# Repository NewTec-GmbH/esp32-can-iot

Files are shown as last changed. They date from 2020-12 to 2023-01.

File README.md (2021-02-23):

# ESP CAN-Analyzer
An ESP32 based interface between CAN-Bus and IoT environments.

This project has the main objective of interfacing a CAN Bus with the user through the use of the Lawicel Protocol (also known as SLCAN). Lawicel represents CAN Frames as strings of ASCII Symbols which can be easily interpreted by the user of by the numerous applications available online. 

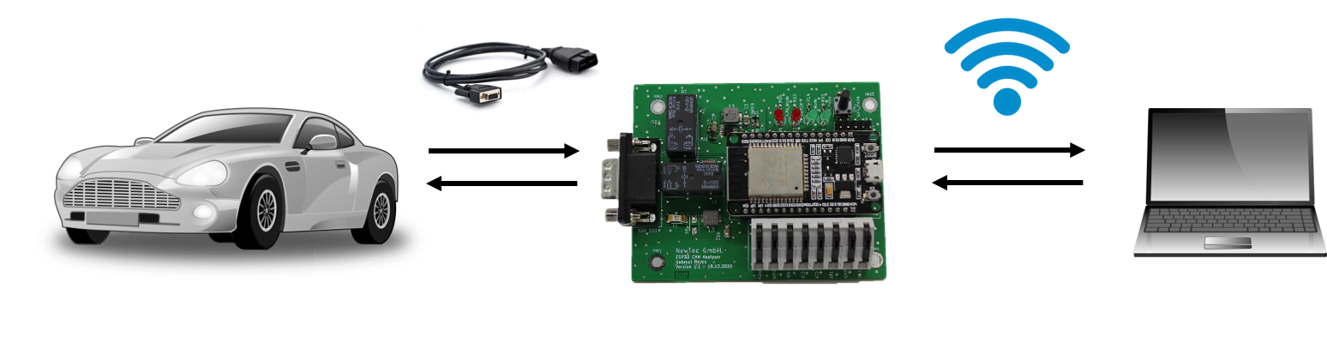
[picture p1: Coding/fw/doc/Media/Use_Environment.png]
Use_Environment


- [Technical Specifications](#Technical-Specifications)
	- [Software Requirements](#Software-Requirements)
	- [Hardware Requirements](#Hardware-Requirements)
	- [Extra/Optional Requirements](#Extra/Optional-Requirements)
- [Context](#Context)
- [Use Case](#Use-Case)
- [Potential Optimization](#Potential-Optimization)
- [Specialized Pages](#Specialized-Pages)

# Technical Specifications 
## Software Requirements
* Support Standard and Extended frame formats
* WiFi Mode Selection (AP or STA)
* Support *Lawicel* Protocol
* HTTP Server over WiFi
* Server shall support authentication
* AP credentials changed through Server
* STA credentials changed through Server
* Bit Timing and Filters changed through Server
* CAN monitoring page (depending on available memory)
* Send CAN frame on demand
* Send CAN frame periodically
* CAN BUS Termination on Demand

## Hardware Requirements
* ESP32-based
* ISO 11898 Compliant (CAN up to 1 Mbps)
* CAN Bus Termination on Demand
* Support CAN through DSUB-9
* Support OBD through DSUB-9
* Bus-off State
* ISO 7637 compliant (Road vehicles -- Electrical disturbances from conduction and coupling)
* Control Button
* Red Error LED
* 4 GPIOs via Clamps

## Extra/Optional Requirements
* Identification of Error Message
* Reset through Webserver (Save and Restart)
* View OBD Messages (.dbc file?)
* LAWICEL over websocket/mqtt (to nodejs/node-red)

# Context
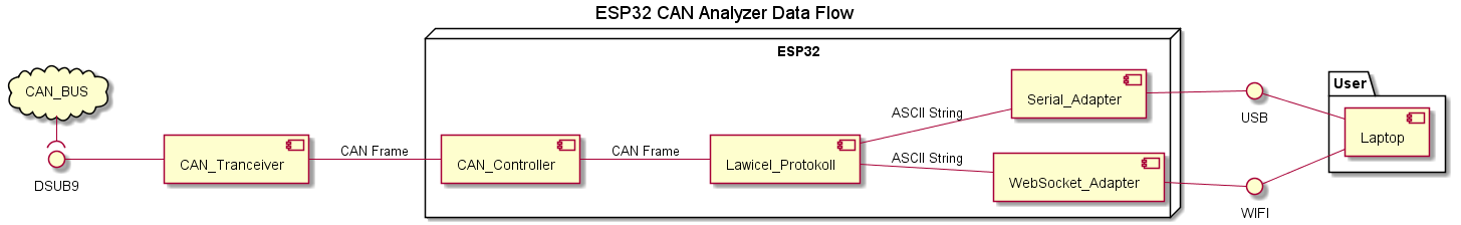
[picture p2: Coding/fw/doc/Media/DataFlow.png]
DataFlow


Based on the Lawicel Protocol, this project connects any standard CAN Bus to the user-end system. One example is its use on the Automotive Environment, where the CAN Bus is acquired through the DSUB-9 connector. The Frames are parsed through Lawicel into an ASCII String and sent through Serial to the Users Laptop. There is a second option, which is sending this String through a Websocket to the user. This enables the use of other IoT tools on the user's side, for example, Node-Red.

# Use Case
UseCaseAnalyzer

The use case for this project is based on the direct connection to a CAN Bus, in order to obtain the information being sent between the members of this bus. On the other side of this communication we find a Serial Interface or a Websocket Interface which presents the information to the user. The user has to provide the device with the characteristics of the Bus it is connected to, in order to correctly acquire the data.

# Potential Optimization

Thisproject has the potential to be improved in many of its aspects, specially its Firmware. These are some of the points that have been noted during the development, which can be improved in order to increase the performance:

* Lawicel commands active during AP Mode
* Use of Binary Lawicel Commands instead of Strings
* Optimize the Websocket Buffering of Messages (in both directions)
* Use of both Cores for Tasking
* Send Cyclic Frames using a Lawicel Command
* Prevent reset after car's start/stop

# Specialized Pages

* [Hardware](./Hardware/README.md)
* [Firmware](./Coding/fw/README.md)
	* [Documentation](./Coding/fw/doc/README.md)
	* [Libraries](./Coding/fw/lib/README.md)
		* [Lawicel Protocol](./Coding/fw/lib/Lawicel/README.md)
		* [CAN](./Coding/fw/lib/CAN/README.md)
	* [Application](./Coding/fw/src/README.md)
	* [Unit Test](./Coding/fw/test/README.md)
* [Glosary](./Coding/fw/doc/Glosary.md)

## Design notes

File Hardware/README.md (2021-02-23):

# Hardware Description

- [Architecture](#Architecture)
- [Implementation](#Implementation)
    - [CAN/OBD-II Switching](#CAN/OBD-II-Switching)
    - [Components](#Components)
    - [Version 1.0](#Version-1.0)
    - [Version 1.1](#Version-1.1)

# Architecture
Hardware_Overview

This deviced is based on the ESP32­-WROOM-­32E processor, which has a diverse number of interfaces such as digital and analog inputs and output, as well as an integrated CAN bus controller and WiFi capabilities, between many other characteristics. The ESP32 additionally needs a CAN Transceiver to receive the data from the CAN-H and CAN-L lines. 

The connection to the CAN Bus is done through a DSUB-9 connector, which is the standard for CAN busses. This connector can also provide a the device with power, but with a 12V voltage which has to be reduced to 5V before going into the ESP32 DevKit, where it will be transformed again into 3.3V.

# Implementation
The Project was developed using KiCad and all its Toolchain. This includes Eeschema, Pcbnew and GerbView.

## CAN/OBD-II Switching
In order to implement this device in the automotive environment it is necessary to adapt the standard connector found in cars (OBD-II) to the standard CAN connector (D-SUB9).
This is achieved by using an OBD-II to DB9 Cable, from Sparkfun for example. The problem with this solution is that the cable does not use the same pins for the High and Low signals of the CAN-Bus:

| Pin | OBD-II | DSUB-9 |
| :---: | :---: | :---: |
| 2 | GND | CAN-LOW |
| 3 | CAN-HIGH | GND |
| 5 | CAN-LOW | --- |
| 7 | --- | CAN-HIGH |
| 9 | 12V | --- |

The main issue is the connection of the CAN signals to Ground, as this would turn off the Bus in all of its nodes and this should be prevented at all costs. 

Our solution is the use of one analog pin on the microcontroller, which detects the incoming 12V at Pin 9 when using the OBD-II option (through a 10:1 voltage divider). If the analog signal is present, two relays are closed to change the connections of the D-SUB9 connector to the rest of the board.

This solution has been proved effective and quick enough so no the bus is not distrubed in any way.

## Components

The following components were selected for this project's PCB. Smaller components such as resistors and capacitors are not included in this list, but can be found on the [BOM](./010_Implementation/BOM.xlsx).

| Component | Description |
| :---: | :---: |
| ESP32-DEVKITC-32D | Microprocessor used. Connected using socket strips |
| SS24 | Safety diode for Microprocessor in case more than one power supply is being used |
| TPS62160DGK | 12V 1A Step-down Converter |
| R452002 | 12V Fuse |
| SMAJ16A | Protective Diode at 12V input |
| G5V-2-DC5 | Relay for "smart" switching between CAN and OBD Pinout |
| BC817 | Transistor for Relay control |
| 1N4148 | Diodes for Relay protection |
| DSUB9 | Standard connector for CAN-Bus |
| SN65HVD233-HT | CAN Transceiver |
| 744242220 | Toroid for CAN-Bus Filtering |
| PESD1CAN | Diode for CAN-Bus Filtering |
| AST 045-08 | 8-position connector with latches for GPIO |
| CAB-10087 | OBD-II to DB9 Cable |

## Version 1.0
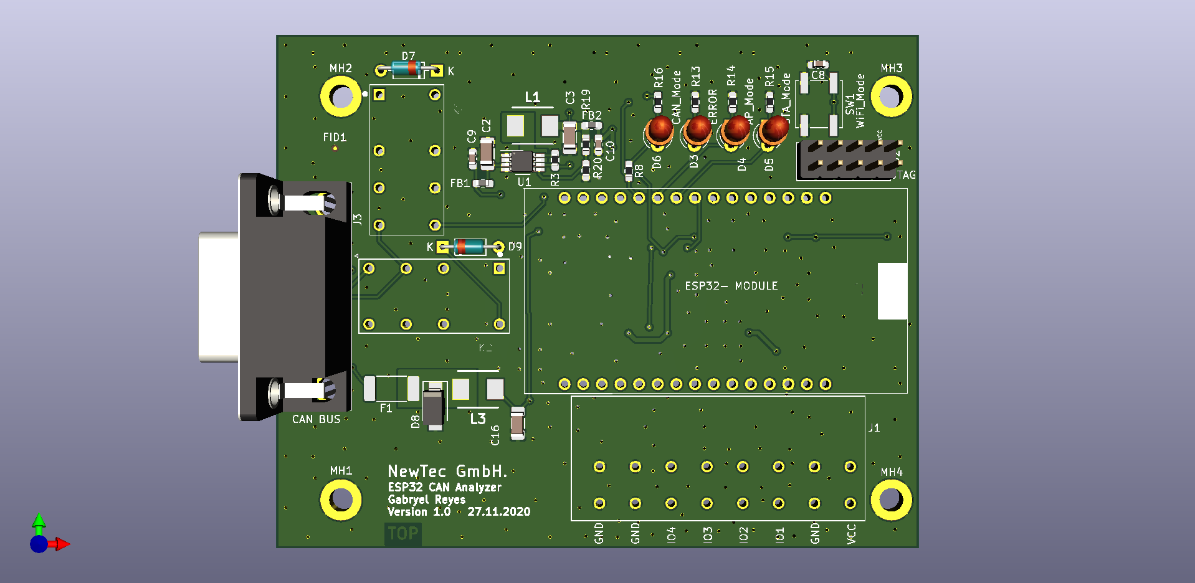
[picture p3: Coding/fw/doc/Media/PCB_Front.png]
Version 1.0_Front
 
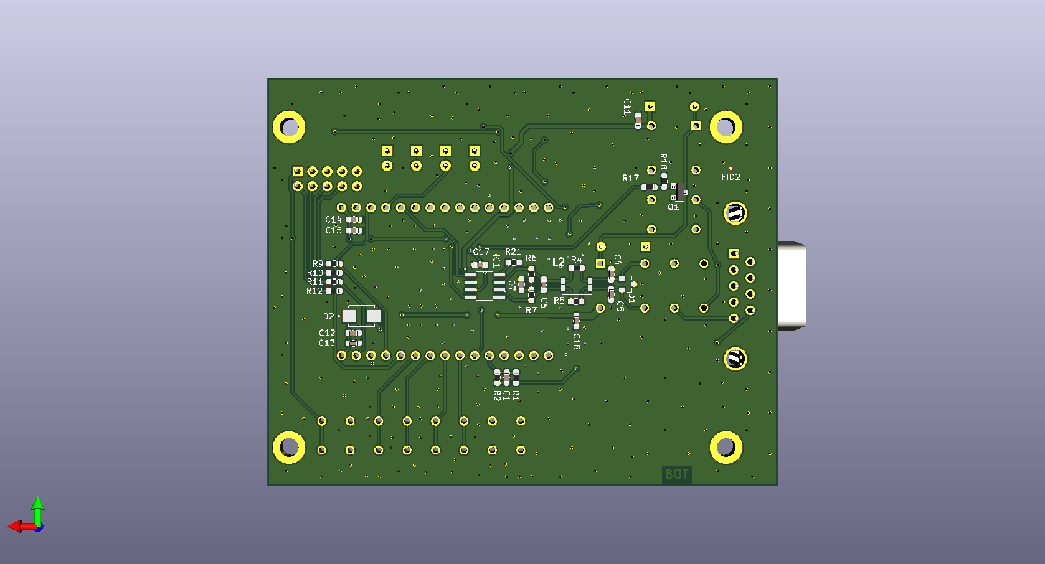
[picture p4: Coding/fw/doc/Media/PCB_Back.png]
Version 1.0_Back


## Version 1.1
2 Main Errors were found on Version 1.0:
* Tx and Rx Signals from the CAN Transceiver were inverted
* The 5V Supply for the Relays was located after a diode, which prevented the use of the relays when connected only through USB Supply. 

In the new version were these two changes made and after testing it resolved in success.

Other minor errors were also repaired, such as the size of the holes for AST 045-08 Connector which were too small.

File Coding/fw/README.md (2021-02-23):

# Firmware Description

- [Software Architecture](#Software-Architecture)
	- [Software Overview](#Software-Overview)
	- [Applicaton Entry Points Processing](#Applicaton-Entry-Points-Processing)
- [Detailed Design](#Detailed-Design)
	- [Main Application](#Main-Application)
	- [Lawicel](#Lawicel)
	- [Web Server](#Web-Server)
	- [Web Socket](#Web-Socket)
- [Software-Hardware Integration](#Software-Hardware-Integration)

# Software Architecture
## Software Overview
Hierarchy

The Firmware is composed by 4 main layers: Application, Modules, Service and HAL. As the software is built on the Arduino Framework, the Arduino.h Library is found on the HAL as the interfacing class between hardware and software. This library contains a great number of sub-libraries which independently control each piece of hardware.

On the Service Layer we can find the Board Class, as an abstraction from the Arduino library to be able to use only the needed GPIO adn their respective methods. Here we can also find the library for the CAN Controller and the IP Stack used by the Webserver.

On the Modules Layer we find the implemented classes: Lawicel and ESPAsyncWebServer, which use the Service Layer to effectively transmit information. Both these Classes are controlled by the Application Layer, which ultimately defines the behavior of the system.

Detailed information on the implemented libraries can be found in the [Library](./lib/README.md) Documentation, as well as online in the case of the Arduino Library.

## Applicaton Entry Points Processing
The following diagram pictures the Entry Points called by the Application while the programm is running. The code where this sequence can be found is contained in the [main.cpp](./src/main.cpp) file. 

MainLoop

The process is divided in two main sections, as per Arduino Framework standard:

### Setup
This section is only called once everytime the system reboots. It initializes the different Modules that compose the system, and expects a Boolean **True** return from each Module in order to continue with the normal routine. If any of the Modules returns a **False** value instead, a System Halt is called from the Board Class.

The Board initialization sets up the HAL by defining which pins are going to be use and their respective modes, for example, Pin 2 is configured as an output in order to be used as the Error LED.

The Lawicel Protocol in its initialization routine also configures each of the Adapters passed as arguments on its constructor. This means that here is the CAN Controller started, as well as the Web Server and Socket when the respective adapter is passed. In the case of having Auto-start configured in Lawicel, the saved parameters are retrieved from the NVM and set up accordingly. Each of these processes is expected to return a **True** value. 

### Loop
As its name describes, the loop is called in a cyclic manner every time it finished its routine. 
Here is the Lawicel Cycle called, where the communication from/to the user occurs. In this case a **False** response does *NOT* call a System Halt, but only a blink on the Error LED as this means the user entered an invalid command. 

The Loop is also constantly checking on the Wireless connection to the configure network to ensure no data-loss. 

Finally, it checks if a system restart is called from the Captive Portal. If this is the case, all modules are halted and the OS is restarted.  

# Detailed Design
## Main Application
The system follows the following procedure during the Setup:

Setup

As mentioned on the Software Architecture, during the Setup Process, any error or **False** return value will call a System Halt, as the configuration of each module is critical for the correct operation of the whole system. 

## State Machine
The ESP CAN-Analyzer has two main modes, AP-Mode and STA-Mode. AP refers to Access Point, where the ESP creates its own Wireless Network and serves only a Captive Portal to work as a Configuration Portal for the STA Credentials. On the other side, STA is the abbreviation for Station, which is the normal mode for the system. The Station Mode uses the user's WiFi credentials to connect to the wireless local network. This mode works as a server through which the Lawicel Protocol can communicate using a websocket.

StateMachine

## Lawicel

The Lawicel Module implements one of the most important components of this project. The Lawicel Protocol is used to communicate witha CAN Bus using ASCII symbols, as each command that is sent has a specific format, as described in the Library's Documentation. 

The module is composed by 4 main components: the implementation of the protocol, an interface for serial communication, an interface for CAN communication and an interface for Non-Volatile Memory. These Interfaces define the functions that the adapters must perform and are directly used by the protocol. Through the use of these, it is possible to handle the Lawicel Module as a completely independent component to which different adapters can be connected depending on the case and hardware used.

Arch_Lawicel

In this case, the adapters are implemented for the ESP32 and the libraries used by it. In the case of the Serial Adapter, it employs directly the Serial hardware from the Arduino Library; however a Web Socket Adapter is also implemented in order to communicate with other IoT systems. For the NVM Adapter, the ESP32 offers a library for managing flash memory using keys, which is called "Preferences". Finally the CAN Adapter is an abstraction from sandeepmistry's [arduino-CAN](https://github.com/sandeepmistry/arduino-CAN), which manages the memory-mapped SJA1000 CAN Controller.

## Web Server
The second most important module is the Webserver. The ESP32 offers the capability of hosting a server that manages the requests asynchron, meaning that it does not block the other tasks that the processor has to complete. This server is an implementation of me-no-dev's [ESPAsyncWebServer](https://github.com/me-no-dev/ESPAsyncWebServer).

Arch_Webserver

The server uses 3 service classes: 
* **WebConfig** contains the constants and important configurations required by the server, such as the possible HTTP Responses. 
* **WebSocket** handles the communication between the client and the WebSocket Adapter for Lawicel.
* **Pages** configures the handling of the Webpages for STA Mode. 
* **Captive Portal** is initiated when AP Mode is active instead, in order to provide the users with an interface to change the credentials for the Station Mode. 
	* Both of these classes, Pages and Captive Portal, use the Serial Peripheral Interface Flash File System (SPIFFS) which stores the Webpages as HTML files and serves them to the web clients when requested.

Arch_Webpages

## Web Socket
As a substitution of the SerialAdapter, a WebSocketAdapter has been implemented. The goal of this is to communicate through the WebServer into a Webpage or an external IoT application (such as Node-Red). The Library for this implementation is included on the AsyncWebServer Library.

Arch_Websocket

# Software-Hardware Integration
Regarding the software, the device sets different LEDs as to show the state of the system, for example to show when a system critical error has occurred or when the Access Point Mode is enabled. The system also has communication with a CAN Transceiver which performs the connection to the bus. The user plays an important role as the they must configure the bus characteristics as well as the needed credentials for the Station Mode. 

UseCaseSoftware

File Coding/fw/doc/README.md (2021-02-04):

# Documentation
This folder contains the Documentation for the ESP32 CAN-Analyzer Project. 

## Design
The Project is described using numerous UML Diagrams in order to give a better image and perspective of how Software and Hardware are composed. These are written using PlantUML and are included in several of the ReadMe files on this project. 

## Software Environment
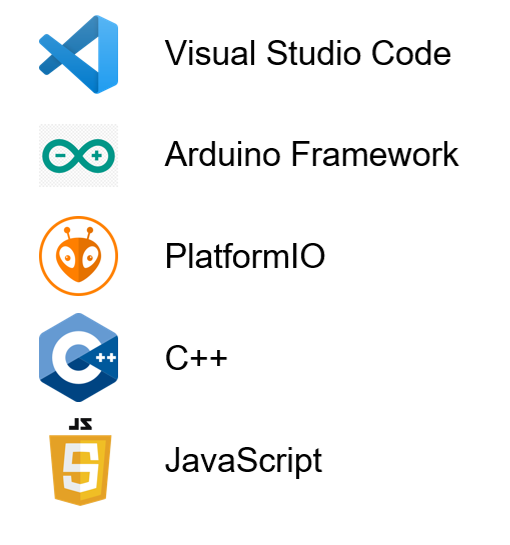
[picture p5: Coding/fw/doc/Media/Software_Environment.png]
Software Environment


This project has been developed using PlatformIO IDE as a plugin of Visual Studio Code. This platform provides the libraries and drivers needed to work with the chosen microcontroller. 

The Firmware has been written using C++, while the Web-application has been developed using JavaScript.

## Doxygen
The software for this project has been documented using Doxygen, using a [Doxyfile](./doxyfile) to store the configuration. 
It is possible to parse the Documentation using the [Doxywizard](https://www.doxygen.nl/download.html) Programm and this configuration file.

## Media
This folder contains images of the project

## Node-Red
Here are the referencial images and Flows for the complementary Node-Red Flows

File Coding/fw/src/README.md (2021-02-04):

# Main Application
The ESP32 CAN-Analyzer main application is composed of the Main Loop, and the Adapters corresponding to the Lawicel Interfaces for Serial, NVM and CAN Modules. These Adapters are specific to the platform, hardware and libraries being used.

- [Main Loop](#Main-Loop)
- [Adapters](#Adapters)
    - [CAN Adapter](#CAN-Adapter)
    - [NVM Adapter](#NVM-Adapter)
    - [Serial Adapter](#Serial-Adapter)

# Main Loop
This contains the standard Arduino "Setup" and "Loop" functions, which control the whole program. The instances of the Adapters and the Lawicel Protocol are also defined in this file. It is important to note that the application stops running if a catastrophioc error is encountered, for example, being unable to connect to the user-given Wireless Network

# Adapters
These are the implementations of the Lawicel Interfaces. The Protocol required one adapter of each kind to work properly:

## CAN Adapter
This file contains the methods used by the CAN Controller. 

Its objetive is to receive the Frames from the Bus and write them in the format of the Frame Struct, which gets passed onto the Lawicel Protocol for its processing. 

On the other side, it also receives the Frames from the Lawicel Protocol which get sent onto the connected Bus.

This section is also responsible for setting the user-selected configuration of the CAN Device, such as Baudrate, Filters, and current Status.

For this project, the Adapter wraps around the [Arduino-CAN](https://github.com/sandeepmistry/arduino-CAN) Library, but it has been copied onto the libs folder to be able to fully implement the Lawicel Commands for the integrated SJA1000 Controller.

## NVM Adapter
This file contains the methods for saving and retrieving data from the non-volatile memory of the ESP32, using the Preferences Library as base.

As there are some parameters that need to be saved between power cycles, such as the wireless credentials, this adapter simplifies and centralizes the access to the saved data. This is achieved using keys and directories to order and store the data, as well as the easy retrieval when requested.

## Serial Adapter
Here is the interface between the Device and Humans found. The Serial Adapter trasmits the output of the Lawicel Protocol, as well as the user input into Lawicel. For the project, two versions of the Serial Adapter have been developed: serialAdapter and WebSocketAdapter. 

SerialAdapter interfaces with the Arduino Serial (UART) interface, while the WebSocketAdapter connects to the WebSocket, so the system can be used through a Wireless network. By default, the WebSocketAdapter is configured.

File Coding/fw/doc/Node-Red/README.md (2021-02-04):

# Node-Red Integration

Node-RED is a programming tool for wiring together hardware devices, APIs and online services in new and interesting ways.

It provides a browser-based editor that makes it easy to wire together flows using the wide range of nodes in the palette that can be deployed to its runtime in a single-click.

For this project, a Node-Red Flow has been developed to monitor the state of a car through its CAN Bus. It is based on using PID Requests to the Car's ECU using the [SAE Standard](https://en.wikipedia.org/wiki/OBD-II_PIDs).

# Data Collection
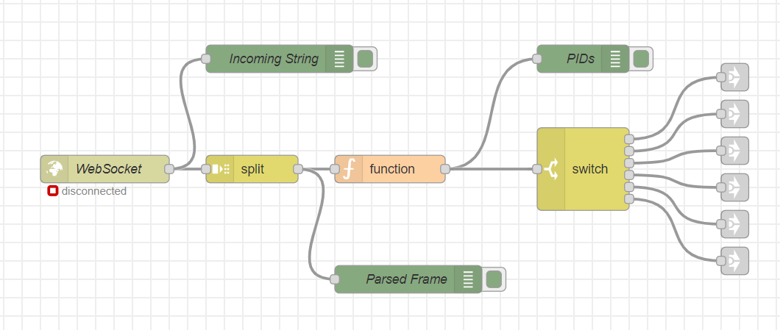
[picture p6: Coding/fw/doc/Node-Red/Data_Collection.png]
Data Collection


This Flow receives the information from the WebSocket and parses the CAN Frame using the Lawicel Protocol. Then only the Frames which comply with the SAE Standard are allowed through to be analyzed/displayed.

# Vehicle Data
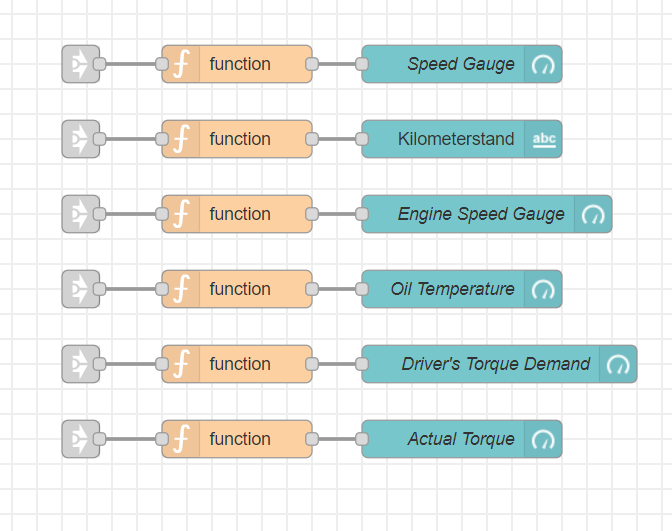
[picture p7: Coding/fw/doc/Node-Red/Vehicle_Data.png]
Vehicle Data


Here are the PIDs received and the Vehicle Data extracted from the Frame's data bytes. Then the information is sent to the Dashboard

# Dashboard
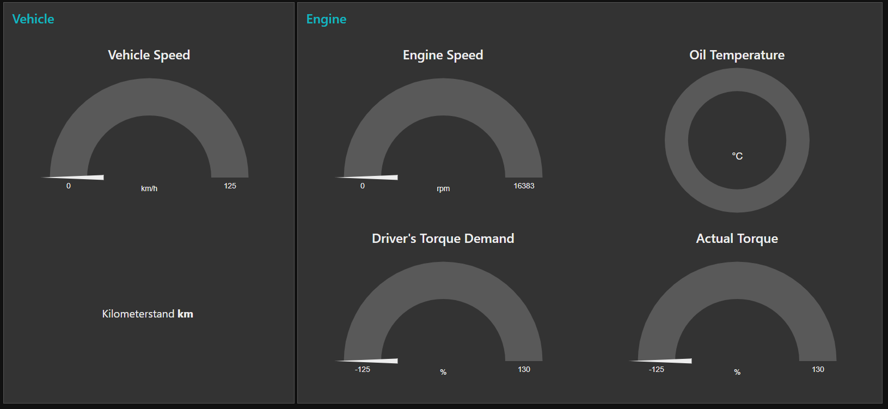
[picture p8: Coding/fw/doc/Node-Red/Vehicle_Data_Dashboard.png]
Dash


The Node-Red Dashboard includes several types of gauges and displays to show the information in the best way possible. Here we have 4 Gauges, one Donut and one text block.

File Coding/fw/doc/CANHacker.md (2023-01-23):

# Connection to CANHacker Software

CANHacker is a Graphical Interface for CAN Adapters that communicate using the Lawicel Protocol, such as this project.

In order to connect to this application, the Serial Adapter must be used instead of the WebSocket.

## Main.cpp
The correct "main.cpp" would look like this:

```cpp

// Includes
#include <Arduino.h>
#include "Lawicel.h"
#include "Board.h"
#include "SerialAdapter.h"
#include "CANAdapter.h"
#include "NVMAdapter.h"

static SerialAdapter gSerialAdapter; /**< Serial Adapter Instance */
static CANAdapter gSja1000Adapter;   /**< CAN Adapter Instance */
static NVMAdapter gFlashAdapter;     /**< NVM Adapter Instance */

/** Lawicel Protocol Instance */
static Lawicel gProtocolLawicel(gSerialAdapter, gSja1000Adapter, gFlashAdapter);

/**
 *  Initialization of Application
 */
void setup()
{
    Board::init();
    if (!gProtocolLawicel.begin())
    {
        Board::haltSystem();
    }
}

/**
 *  Application Loop
 */
void loop()
{   
    gProtocolLawicel.executeCycle();
}
```

## CANHAcker

Using the latest CANHacker Version (V.2.00.02), the connection is performed in two steps:

- Settings Windows: Set the `COM Port`, `Serial Baudrate` (default. 115200 bit/s), and `CAN Baudrate`. Other options such as "Listen Only" and "Timestamp" can be selected here too.

- Connect Button: Performs the connection to the device itself.

To check if your device is succesfully connected, the bottom bar should display the current state as "Connected to <<`CAN Baudrate`>> kbit/s" and the current Firmware Version (current: V1.01)

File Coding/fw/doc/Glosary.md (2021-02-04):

# Glosary

## AP
Abbreviation of Access Point. 
Device that creates a Wireless Area Network (WLAN).

## NVM
Abbreviation of Non-Volatile Memory.
Memory that does not need energy to contain data. The information is still saved even after a power cycle

## STA
Abbreviation of Station.
Device connects itself to a Wireless Area Network.

## SSID
Abbreviation of Service Set Identifier.
Name of the Wireless Area Network to be connected to in Station Mode, or to create as Access Point Mode

## WS
Abbreviation of Web Socket.
Full-Duplex and bidirectional communication protocol for communication through an unique Socket between Client and Server.

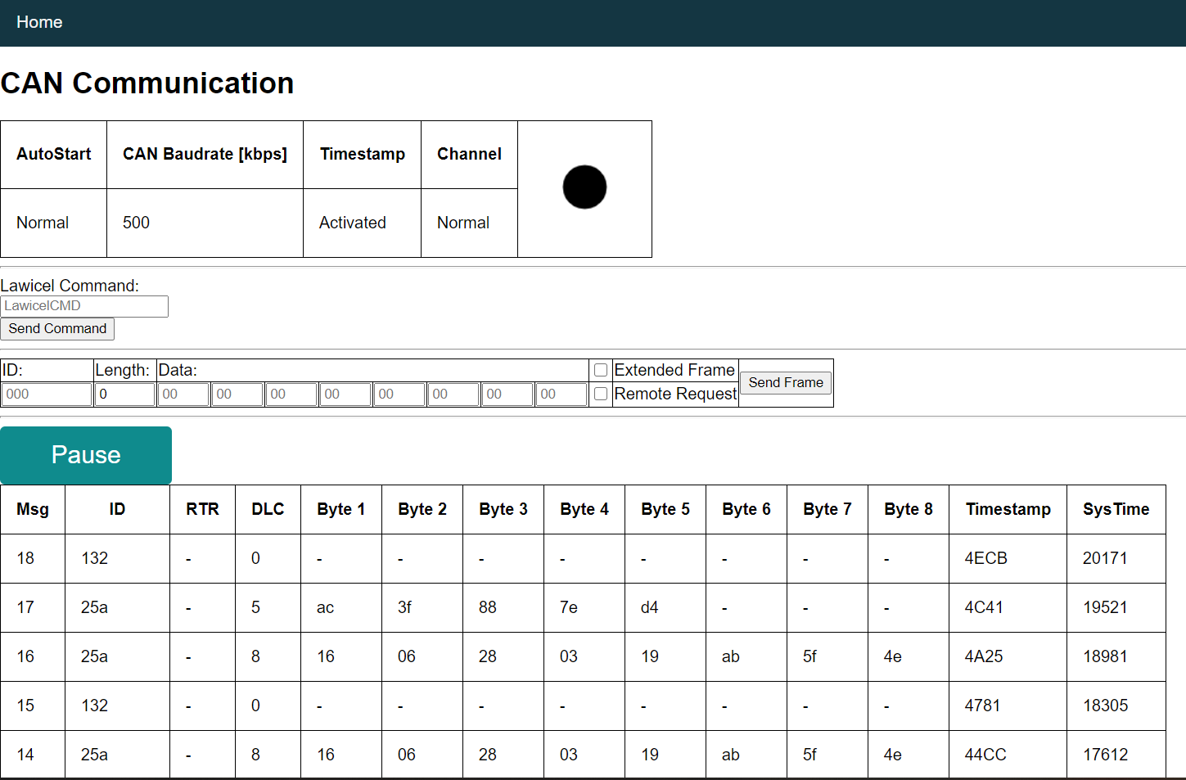
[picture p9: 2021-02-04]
Coding/fw/doc/Media/WebPage Design.png

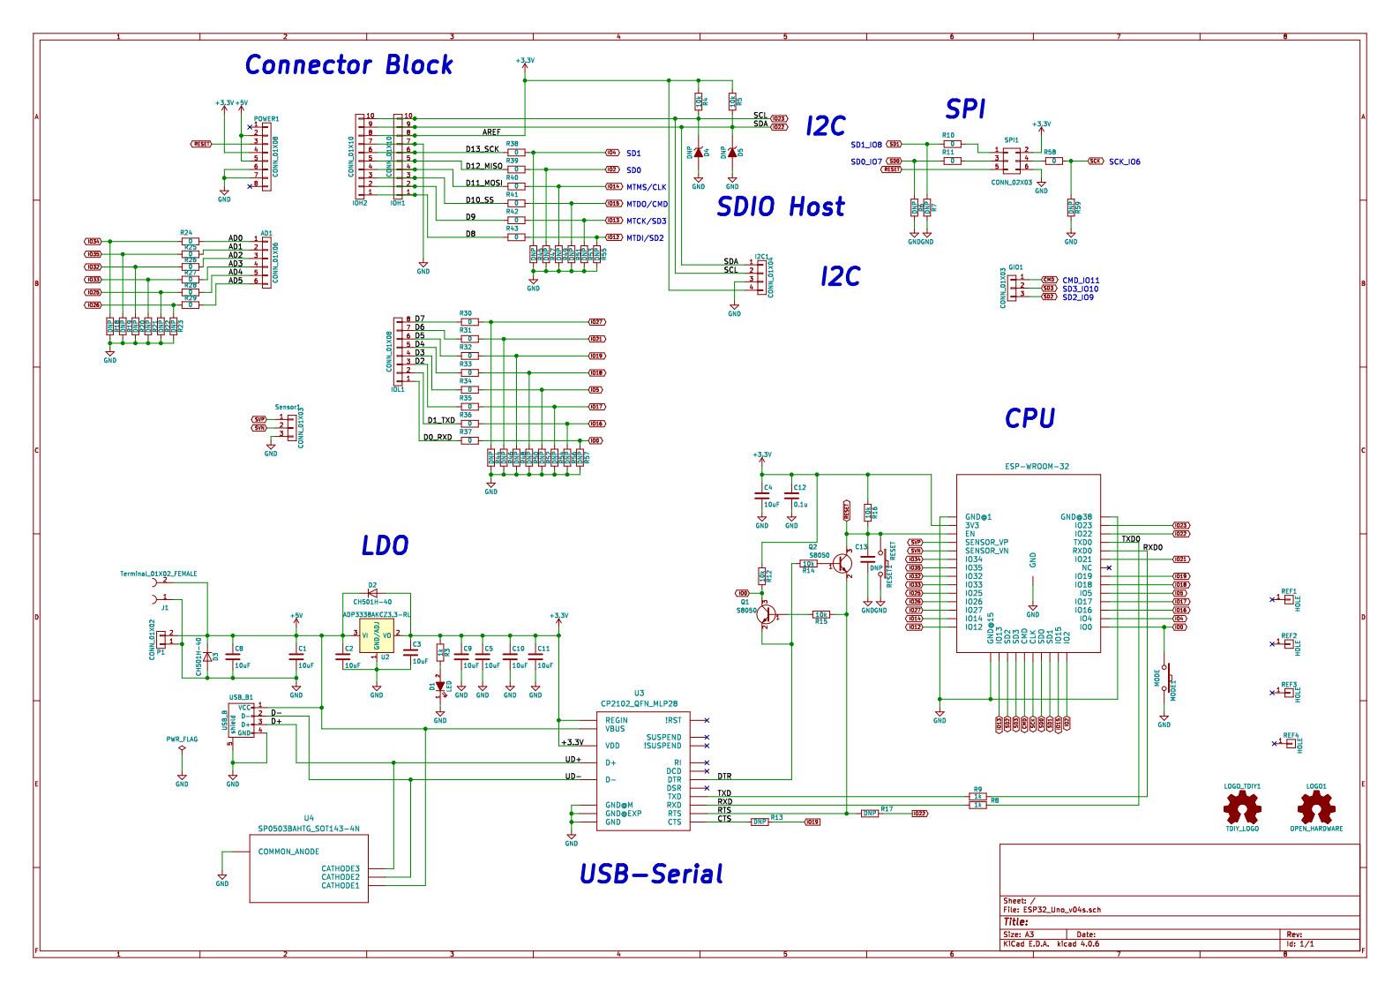
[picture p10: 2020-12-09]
Hardware/040_Data_Sheets/esp32-devkit Schematic.jpg

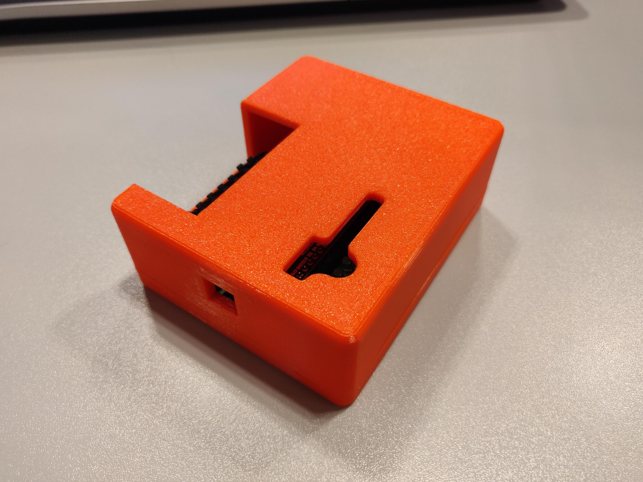
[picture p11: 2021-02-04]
Coding/fw/doc/Media/HW_Case4.png

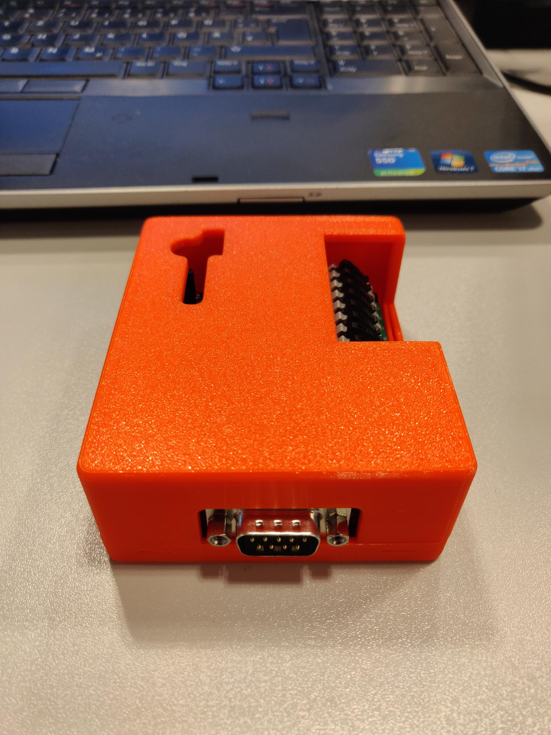
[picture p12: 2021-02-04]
Coding/fw/doc/Media/HW_Case1.png

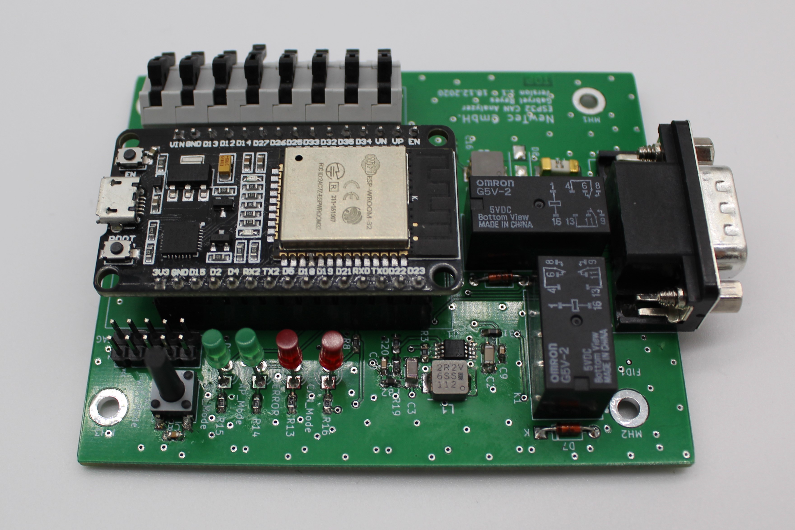
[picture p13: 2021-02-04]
Coding/fw/doc/Media/HW_Final3.jpg

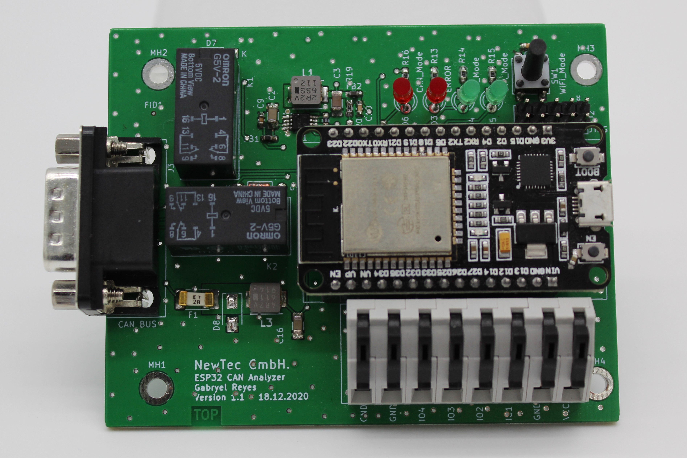
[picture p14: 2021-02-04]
Coding/fw/doc/Media/HW_Final2.jpg

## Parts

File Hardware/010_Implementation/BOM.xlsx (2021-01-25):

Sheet: Board
Id | Designator | Package | Quantity | Designation | NewTec | Digikey
1 | REF**,REF**,REF** | MountingHole_3.2mm_M3_DIN965_Pad | 3 | MountingHole_3.2mm_M3_DIN965_Pad | X
2 | J1 | AST 045-08 | 1 | Conn_01x08_Female | X
3 | K2,K1 | RELAY_G5V-2-DC5 | 2 | G5V-2-DC5 |  | X
5 | L1 | INDPM5550X300N | 1 | 2.2u | X |  | https://www.digikey.de/short/zv370m
6 | L3 | INDPM5550X300N | 1 | 5u | X
7 | U1 | VSSOP-8_3.0x3.0mm_P0.65mm | 1 | TPS62160DGK |  | X
8 | R21,R5,R4 | R_0603_1608Metric_Pad0.98x0.95mm_HandSolder | 3 | 0 | X
9 | R20 | R_0603_1608Metric_Pad0.98x0.95mm_HandSolder | 1 | 180k | X
10 | R19 | R_0603_1608Metric_Pad0.98x0.95mm_HandSolder | 1 | 953k | X
11 | R18 | R_0603_1608Metric_Pad0.98x0.95mm_HandSolder | 1 | 150 | X
12 | R17 | R_0603_1608Metric_Pad0.98x0.95mm_HandSolder | 1 | 430 | X
13 | R16,R15,R14,R13 | R_0603_1608Metric_Pad0.98x0.95mm_HandSolder | 4 | 500 | X
14 | R12,R11,R10,R9 | R_0603_1608Metric_Pad0.98x0.95mm_HandSolder | 4 | 100 | X
15 | R8,R2 | R_0603_1608Metric_Pad0.98x0.95mm_HandSolder | 2 | 1k | X
16 | R7,R6 | R_0603_1608Metric_Pad0.98x0.95mm_HandSolder | 2 | 62 | X
17 | R3,R1 | R_0603_1608Metric_Pad0.98x0.95mm_HandSolder | 2 | 10k | X
18 | C15,C12 | C_0603_1608Metric_Pad1.08x0.95mm_HandSolder | 2 | 1u | X
19 | C17, C14,C13,C11,C10,C9,C8,C1 | C_0603_1608Metric_Pad1.08x0.95mm_HandSolder | 7 | 100n | X
20 | C7 | C_0603_1608Metric_Pad1.08x0.95mm_HandSolder | 1 | 4n | X
21 | C6,C5,C4 | C_0603_1608Metric_Pad1.08x0.95mm_HandSolder | 3 | 100p | X
22 | FB2,FB1 | L_0603_1608Metric_Pad1.05x0.95mm_HandSolder | 2 | Ferrite_Bead | X
23 | C16,C2 | C_1206_3216Metric_Pad1.33x1.80mm_HandSolder | 2 | 10u | X
24 | C3 | C_1206_3216Metric_Pad1.33x1.80mm_HandSolder | 1 | 22u | X
25 | F1 | Fuse_2512_6332Metric_Pad1.52x3.35mm_HandSolder | 1 | R452002 | X
26 | D8 | D_SMA | 1 | SMAJ16A | X
27 | L2 | WE-SLM77 | 1 | 744242220 |  | X
28 | U2 | MODULE_ESP32-DEVKITC-32D | 1 | ESP32-DEVKITC-32D | X
29 | Q1 | SOT-23 | 1 | BC817 | X
30 | D7 | D_DO-35_SOD27_P7.62mm_Horizontal | 1 | 1N4148 | X
31 | D6,D3 | LED_D3.0mm | 2 | RED | X
32 | D2 | DIOM5336X265N | 1 | SS24 | X
33 | SW1 | SW_Push_1P1T_NO_CK_KSC7xxJ | 1 | SW_Push |  | X
34 | J3 | DSUB-9_Female_Horizontal_P2.77x2.84mm_EdgePinOffset4.94mm_Housed_MountingHolesOffset7.48mm | 1 | DSUB9 |  | X
35 | J2 | PinHeader_2x05_P1.00mm_Vertical | 1 | JTAG Jumper Pins |  | X
36 | IC1 | SOIC127P600X175 | 1 | SN65HVD233-HT |  | X
37 | D5,D4 | LED_D3.0mm | 2 | GREEN | X
38 | D1 | SOT23-3 | 1 | PESD1CAN | X

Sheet: Tabelle1
Id | Designator | Designation | Package
2 | J1 | Conn_01x08_Female | AST 045-08
3 | K2,K1 | G5V-2-DC5 | RELAY_G5V-2-DC5
5 | L1 | 2.2u | INDPM5550X300N
6 | L3 | 5u | INDPM5550X300N
7 | U1 | TPS62160DGK | VSSOP-8_3.0x3.0mm_P0.65mm
8 | R21,R5,R4 | 0 | R_0603_1608Metric_Pad0.98x0.95mm_HandSolder
9 | R20 | 180k | R_0603_1608Metric_Pad0.98x0.95mm_HandSolder
10 | R19 | 910k | R_0603_1608Metric_Pad0.98x0.95mm_HandSolder
11 | R18 | 150 | R_0603_1608Metric_Pad0.98x0.95mm_HandSolder
12 | R17 | 430 | R_0603_1608Metric_Pad0.98x0.95mm_HandSolder
13 | R16,R15,R14,R13 | 510 | R_0603_1608Metric_Pad0.98x0.95mm_HandSolder
14 | R12,R11,R10,R9 | 100 | R_0603_1608Metric_Pad0.98x0.95mm_HandSolder
15 | R8,R2 | 1k | R_0603_1608Metric_Pad0.98x0.95mm_HandSolder
16 | R7,R6 | 62 | R_0603_1608Metric_Pad0.98x0.95mm_HandSolder
17 | R3,R1 | 10k | R_0603_1608Metric_Pad0.98x0.95mm_HandSolder
18 | C15,C12 | 1u | C_0603_1608Metric_Pad1.08x0.95mm_HandSolder
19 | C18,C17,C14,C13,C11,C10,C9,C8,C1 | 100n | C_0603_1608Metric_Pad1.08x0.95mm_HandSolder
20 | C7 | 3,3n | C_0603_1608Metric_Pad1.08x0.95mm_HandSolder
21 | C6,C5,C4 | 100p | C_0603_1608Metric_Pad1.08x0.95mm_HandSolder
22 | FB2,FB1 | Ferrite_Bead | L_0603_1608Metric_Pad1.05x0.95mm_HandSolder
23 | C16,C2 | 10u | C_1206_3216Metric_Pad1.33x1.80mm_HandSolder
24 | C3 | 22u | C_1206_3216Metric_Pad1.33x1.80mm_HandSolder
25 | F1 | R452002 | Fuse_2512_6332Metric_Pad1.52x3.35mm_HandSolder
26 | D8 | SMAJ16A | D_SMA
27 | L2 | 744242220 | WE-SLM77
28 | U2 | ESP32-DEVKITC-32D | MODULE_ESP32-DEVKITC-32D
29 | Q1 | BC817 | SOT-23
30 | D7 | 1N4148 | D_DO-35_SOD27_P7.62mm_Horizontal
31 | D6,D3 | RED | LED_D3.0mm
32 | D2 | SS24 | DIOM5336X265N
33 | SW1 | SW_Push | SW_Push_1P1T_NO_CK_KSC7xxJ
34 | J3 | DSUB9 | DSUB-9_Female_Horizontal_P2.77x2.84mm_EdgePinOffset4.94mm_Housed_MountingHolesOffset7.48mm
35 | J2 | JTAG Jumper Pins | PinHeader_2x05_P1.00mm_Vertical
36 | IC1 | SN65HVD233-HT | SOIC127P600X175
37 | D5,D4 | GREEN | LED_D3.0mm
38 | D1 | PESD1CAN | SOT23-3

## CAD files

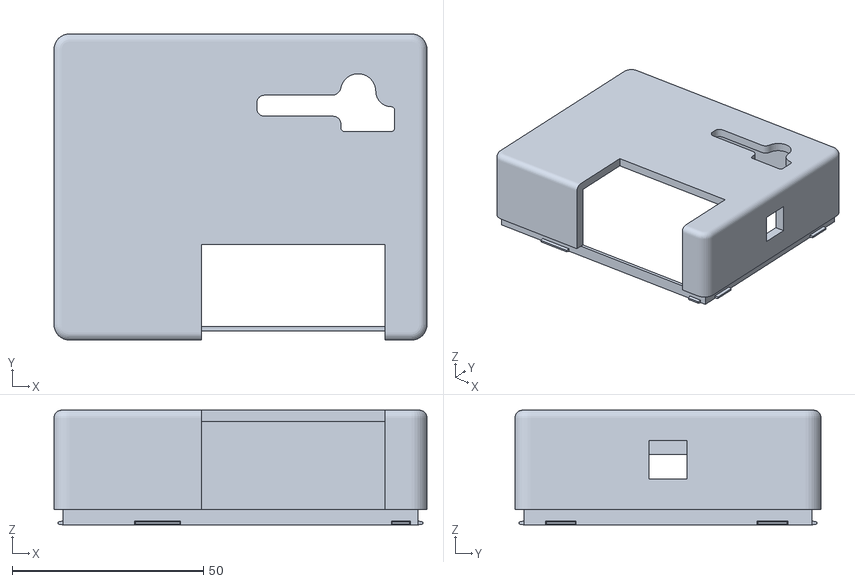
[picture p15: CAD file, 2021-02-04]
Hardware/030_3D_Modell/Casing_Top.stl
97.5 x 80.0 x 30.0

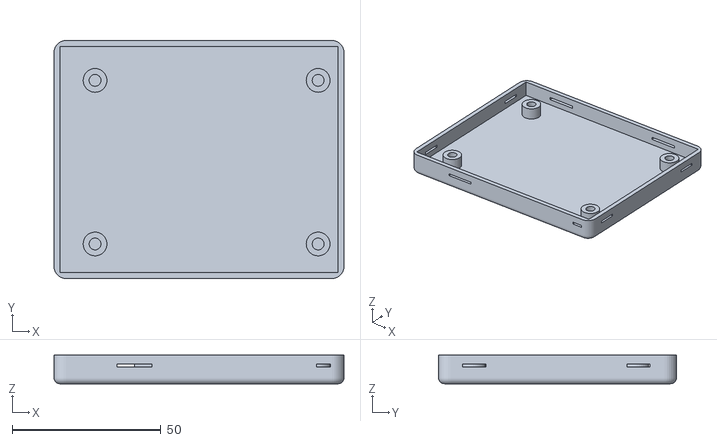
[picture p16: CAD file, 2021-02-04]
Hardware/030_3D_Modell/Casing_Bot.stl
97.5 x 80.0 x 9.60

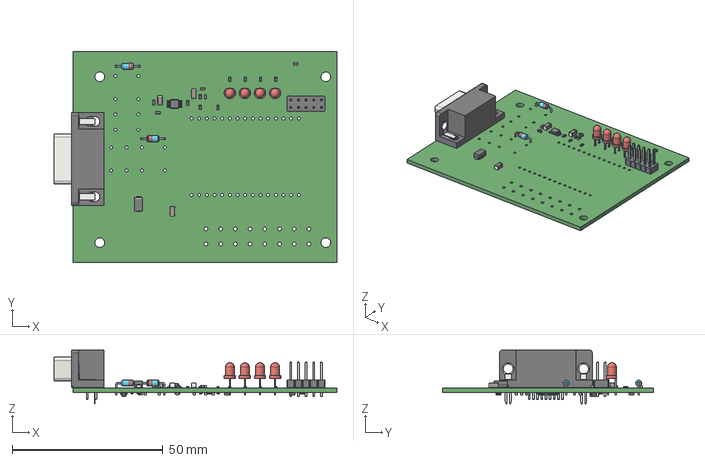
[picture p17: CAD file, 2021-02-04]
Hardware/030_3D_Modell/Board.step
93.9 x 70.0 x 17.9 mm

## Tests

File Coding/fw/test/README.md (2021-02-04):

# Unit Testing
This directory is intended for PIO Unit Testing and project tests.

# Purpose
Unit Testing is a software testing method by which individual units of
source code, sets of one or more MCU program modules together with associated
control data, usage procedures, and operating procedures, are tested to
determine whether they are fit for use. Unit testing finds problems early
in the development cycle.

More information about PIO Unit Testing:
https://docs.platformio.org/page/plus/unit-testing.html

# Test Environment
In the [platformio.ini](../platformio.ini) file is the *native* environment defined in order to run these tests. This means that the unit tests are not run on the ESP32 but on Windows. 

For this to work is necesary to install a [C++ Compiler](https://dev.to/gamegods3/how-to-install-gcc-in-windows-10-the-easier-way-422j) and use the [Test](../lib/Test) Library in order to emulate the Arduino native libraries.

# Test Main
In this page are located the Tests which are going to be executed. 
The "main" function calls the individual tests between an UNITY_BEGIN() and UNITY_END() commands.
Each Test contains individual checks depending for each variable that we want to observate.
For example:
- TEST_ASSERT_TRUE(condition): Checks if in the current state the condition is true.
- TEST_ASSERT_EQUAL(expected, current): Checks if the current value equals the expected value.

If any of these checks fail, the whole test will be failed and the main function skips onto the next test.

In this case we are testing the possible Lawicel Commands that can be sent to the Device, for example:

```cpp
void test_version(void)
{
    runProtocolExecute(testingSerialAdapter.writeInput("V"));
    TEST_ASSERT_EQUAL_STRING("V0101\r", testingSerialAdapter.m_outputString.c_str());
}
```
The input Command "V" is written as input for the Lawicel Protocol, and gets processed. The result should be a serial output of V followed by the Software Version (0101 in this case), and with '\r' as terminator (as Lawicel specifies). The TEST_ASSERT_EQUAL_STRING method compared the expected string (first parameter) with the output string after the command gets processed (second parameter). If everything works as intended, the check is successful and the Test is Passed.

# Test Adapters
Are the implementations of the Lawicel Interfaces in order to test inputs and outputs of the Protocol.

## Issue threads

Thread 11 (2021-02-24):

Fix all doxygen warnings

BlueAndi, 2021-02-24:
Please fix all doxygen warnings, here are some of them, but not all:

```
esp32-can-iot/Coding/fw/src/Adapters/CANAdapter.h:70: warning: argument 'm_baudrate' of command @param is not found in the argument list of CANAdapter::CANAdapter()
esp32-can-iot/Coding/fw/src/Adapters/CANAdapter.h:123: warning: argument 'Frame' of command @param is not found in the argument list of CANAdapter::send(const Frame &frame)
esp32-can-iot/Coding/fw/src/Adapters/CANAdapter.h:128: warning: The following parameters of CANAdapter::send(const Frame &frame) are not documented: parameter 'frame'
```

To get all violations, please enable locally the extraction of the private methods and members too.

Closed 2023-01-21.

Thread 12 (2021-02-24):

Remove temporary files and backup files

BlueAndi, 2021-02-24:
Please remove temporary files and backup files in
```esp32-can-iot/Hardware/010_Implementation/```

Is the desktop.ini file in the root folder necessary?

gabryelreyes, 2021-02-25:
Desktop.ini file deleted.
Files in /Hardware/010_Implementation/ were packed in a ZIP, without the backup files, to reduce size.

BlueAndi, 2021-02-25:
.zip not necessary. Some files are ASCII files you could diff them for changes. With the .zip you won't have this advantage.

Closed 2023-01-21.

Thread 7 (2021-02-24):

The out variable "result" shall not be changed in error case.

BlueAndi, 2021-02-24:
https://github.com/NewTec-GmbH/esp32-can-iot/blob/7d3f17cc18107fe80ecb2b8c116964ef7bebb800/Coding/fw/lib/Lawicel/Lawicel.cpp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

The "result" variable may be a uninitalized and the computed value will be garbage in line 220.
The variable itself should never be changed in case of an error.

Closed 2023-01-21.

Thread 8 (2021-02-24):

Invalid parameter description + unnecessary string copy on stack

BlueAndi, 2021-02-24:
https://github.com/NewTec-GmbH/esp32-can-iot/blob/7d3f17cc18107fe80ecb2b8c116964ef7bebb800/Coding/fw/lib/WebServer/CaptivePortal.cpp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

The parameters are not correct described in the function comment.
Additional both parameters are copied to the stack, which shall be avoided.

Closed 2023-01-21.

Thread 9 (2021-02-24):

Unnecessary copy of parameter to stack.

BlueAndi, 2021-02-24:
https://github.com/NewTec-GmbH/esp32-can-iot/blob/7d3f17cc18107fe80ecb2b8c116964ef7bebb800/Coding/fw/lib/Settings/FlashMem.cpp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

Constant string "defaultValue" is copied to stack, which shall be avoided.

Closed 2023-01-21.

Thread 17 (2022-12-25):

Build error

Slenkis, 2022-12-25:
### My ```platformio.ini``` file:
```ini
[env:esp32_HW_Ver_1.1]
platform = espressif32
board = esp32dev
framework = arduino
upload_port = COM20
monitor_port = COM20
monitor_speed = 115200
lib_deps =
    me-no-dev/AsyncTCP@^1.1.1
    me-no-dev/ESP Async WebServer@^1.2.3
    CAN
    FS
    SPIFFS
    DNSServer
build_flags=
    -std=c++11
    -Wall
    -Wextra
    -O3
    -Wl,-Map,firmware.map
    -Ilib/Lawicel
    -Ilib/WebServer
    -Isrc/Adapters
    -Ilib/IO
    -Ilib/Settings
build_unflags =
    -Os
    -g3
lib_ignore =
    Test
```
### Build log: https://pastebin.com/huNsGX4y

OS: Win10 PRO x64 21H2
VSCode: v1.74
PlatformIO: 6.1.5
 - framework-arduinoespressif32 @ 3.20005.220925 (2.0.5)
 - tool-esptoolpy @ 1.40201.0 (4.2.1)
 - toolchain-xtensa-esp32 @ 8.4.0+2021r2-patch3

gabryelreyes, 2022-12-25:
Hi, this project has not been worked on for some time, and there has been some breaking changes since then. But I may have found a quick fix: Add `#include <Websocket.h>` to main.cpp

If you then get [this](https://github.com/me-no-dev/ESPAsyncWebServer/issues/1147) error: Change your platformio.ini to use older platform version: `platform = espressif32@3.5.0`

Slenkis, 2022-12-25:
I'm trying to use your project in a bundle of esp32 + vp230... for CAN Hacker v2.00.02 via USB

I downgraded the version, removed the build flags and moved the library dependency to include. now it is assembled without errors.

`platformio.ino`:
```ino
[env:esp32_HW_Ver_1.1]
platform = espressif32 @ ~3.5.0
board = az-delivery-devkit-v4
framework = arduino
upload_port = COM8
monitor_port = COM8
monitor_speed = 115200
lib_deps =
    me-no-dev/AsyncTCP@^1.1.1
    me-no-dev/ESP Async WebServer@^1.2.3
    CAN
    FS
    SPIFFS
    DNSServer
lib_ignore = Test
```

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

Slenkis, 2022-12-25:
Now there is a problem when reading NVS settings..
In serial port after reset:
```
rst:0x1 (POWERON_RESET),boot:0x12 (SPI_FAST_FLASH_BOOT)
configsip: 0, SPIWP:0xee
clk_drv:0x00,q_drv:0x00,d_drv:0x00,cs0_drv:0x00,hd_drv:0x00,wp_drv:0x00
mode:DIO, clock div:2
load:0x3fff0018,len:4
load:0x3fff001c,len:1044
load:0x40078000,len:10124
load:0x40080400,len:5828
entry 0x400806a8
[E][Preferences.cpp:472] getString(): nvs_get_str len fail: SerialBaud NOT_FOUND
10.1.1.183
WebSocket client #1 connected from 10.1.1.2
[E][Preferences.cpp:472] getString(): nvs_get_str len fail: CanBaud NOT_FOUND
[E][Preferences.cpp:472] getString(): nvs_get_str len fail: CanBaud NOT_FOUND
```
In browser:
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

# &

CAN Hacker connected to esp, but it cannot receive and send packets

gabryelreyes, 2022-12-25:
The NVS Errors are not fatal. This just means that there are no parameters stored on the NVS yet.
Regarding Sending and Receiving, are you correctly setting your Baudrate and Opening the CAN Channel using the Lawicel Commands?

Regarding the errors on the Web Interface, you can open the web console to read which errors occur in the Javascript code of the frontend

Slenkis, 2022-12-25:
When send Lawicel Command ("D[CR]") from browser:
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

resistance between CAN L and CAN H = 60omh,
voltage between CAN L (or CAN H) and GND = 1.5v (!!!!)

gabryelreyes, 2022-12-25:
This should not have anything to do with CAN, as the D command was only implemented to read the current status of the system and send it to the web interface periodically. It has no influence on the Bus itself: [implementation here](https://github.com/NewTec-GmbH/esp32-can-iot/blob/25d864e3779b2deda0d8252bbd4cc9b17b63a298/Coding/fw/lib/Lawicel/Lawicel.cpp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)

You could try activating the auto-start, in that way the start values will be saved in the NVM.

gabryelreyes, 2022-12-25:
Have you opened the CAN Channel? Looks like you have not (from the screenshot of the console). That could explain the voltages you are reading.

Please read the Lawicel Documentation on how to open the channel ("S" command to set a Baudrate. "O" command to open the channel)

You could try sending S6 to set it to 500 kbps, and then O to open the channel. And then measure again.

Slenkis, 2022-12-25:
Channel does not open..

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

Slenkis, 2022-12-25:
<details>
  <summary>From Arduino to ESP</summary>
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
</details>

gabryelreyes, 2022-12-25:
Are you receiving any confirmation or message each time you send a command? The console should be answer with OK or Error each time you try to open the channel.

Could you please try it using the Serial Interface?

``` cpp
static Lawicel gProtocolLawicel(gSerialAdapter, gSja1000Adapter, gFlashAdapter);

void setup()
{
    Board::init();
    if (!gProtocolLawicel.begin())
    {
        Board::haltSystem();
    }
}

void loop()
{
    if (!gProtocolLawicel.executeCycle())
    {
        Board::blinkError(250);
    }
}

```

Then you can send S6 and O through the serial monitor, and it should answer with 0x13 (OK) or 0x07 (Error).

If this works and you can send messages, then the problem is in the websocket, but if it does not work and you cannot send messages with it, then the problem is somewhere else.

Slenkis, 2022-12-25:
I am open Arduino IDE serial monitor, reset ESP32 and send `O[CR]`. I didn't get anything in response...

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

gabryelreyes, 2022-12-25:
Does the Serial Monitor append the `[CR]` automatically, or are you writing it yourself? Normally the Serail monitor appends it but it could you could have a different configuration

Slenkis, 2022-12-25:
Without `[CR]` word after `O` (see photo) the result has not changed..

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

gabryelreyes, 2022-12-25:
Yes, you dont have to write the word `CR` but only `O`. But this is weird, as I just tested it and the ESP32 responds as it should.

Have you tested the ESP32 with the VP230 using only a CAN Bus Example? [Example](https://github.com/sandeepmistry/arduino-CAN/blob/master/examples/CANReceiver/CANReceiver.ino)

I do not have a transceiver with me right now in order to further diagnose your problem, but I will test in a couple of day as soon as I have one.

gabryelreyes, 2022-12-25:
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

This is the desired response:
Sent `S6`. Responded `0D`
Sent `O`. Responded `0D`
Sent `C`. Responded `0D`
(... Repeated that a couple of times to check it works...)

Sent `C` after is another `C`. Responded `07` (Error) as the CAN channel was already closed.

Slenkis, 2022-12-25:
May be my vp230 is died after installing in mcp2515 (5v vin)..

Slenkis, 2022-12-25:
in arduino this framework: https://github.com/autowp/arduino-canhacker

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

gabryelreyes, 2022-12-25:
Resistance and Voltage are sadly not a good indicator for CAN Bus given that it is a high speed bus. It would be better to inspect it using an oscilloscope instead.

Were you able to use the example I posted before? With it you can be certain that your hardware/tranceiver/connections work.

Slenkis, 2022-12-25:
esp32 + vp230 and can example. from elm327 send packet with data=2323 (dec)
serial monitor 115200baud: https://pastebin.com/nBB9AwCp (infinity messages)

gabryelreyes, 2022-12-25:
Okay so the hardware works :D As I mentioned before, I do not have the means to test this further right now, but I will on the next couple of days. I am sorry you have this problem and I will try to tackle this as soon as I can

Slenkis, 2022-12-25:
ESP32 send packets to Arduino (script from example folder)

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
Slenkis, 2022-12-29:
can you send a photo of how your vp230 is connected to the esp32?

gabryelreyes, 2022-12-29:
I am using the Hardware developed for this project. You can see all the schematics and pictures in the [hardware](./Hardware) folder, using KiCad. But the connections are the same as in the CAN library and the same that you have: 4 is CRX and 5 is CTX. Do you have any other pins available in the transceiver? Maybe you are in loopback mode or sleep mode. Check the datasheet please. And as I mentioned, try to get the examples of the CAN library to work and then come back to this project

gabryelreyes, 2022-12-29:
Please check [this](https://github.com/sandeepmistry/arduino-CAN/issues/75) is not your case.

gabryelreyes, 2023-01-23:
Documentation on the connection to CANHacker can be now found [here](https://github.com/NewTec-GmbH/esp32-can-iot/blob/master/Coding/fw/doc/CANHacker.md)

Slenkis, 2023-01-25:
> Documentation on the connection to CANHacker can be now found [here](https://github.com/NewTec-GmbH/esp32-can-iot/blob/master/Coding/fw/doc/CANHacker.md)

### Code from the [documentation](../blob/master/Coding/fw/doc/CANHacker.md) doesn`t build because there are no necessary libraries

#### BUILD is OK, imports from master branch:

```cpp
#include <Arduino.h>
#include "Lawicel.h"
#include "SerialAdapter.h"
#include "CANAdapter.h"
#include "NVMAdapter.h"
#include "WebSocketAdapter.h"
#include "Board.h"
#include "WLAN.h"
```

#### BUILD is FAILED, imports from [md](../blob/master/Coding/fw/doc/CANHacker.md):

```cpp
#include <Arduino.h>
#include "Lawicel.h"
#include "Board.h"
#include "SerialAdapter.h"
#include "CANAdapter.h"
#include "NVMAdapter.h"
```

Slenkis, 2023-01-25:
and my Aduino uno + MCP2515 (with tja1050) + [this scetch](https://github.com/autowp/arduino-canhacker/blob/master/examples/softwareserial_debug/softwareserial_debug/softwareserial_debug.ino) => now is working... im mix up CAN H and L wires.. sorry

my esp32 + vp230 + [your code after fix](https://github.com/NewTec-GmbH/esp32-can-iot/blob/master/Coding/fw/doc/CANHacker.md) => now he listens to packets, but he can't send anything... CTX pin has 3.3v, CRX has 1.8v; can H & L pins has 1.5v if transiver not connected to can bus

gabryelreyes, 2023-01-28:
The fix not building is a sad inconvinience, but it should not have an effect on the functionality of the library. In the upcoming weeks I will fix all those build and configuration issues. Thanks for bringing this to my attention 👍

Regarding your vp230 problem, make sure you check the following:

- [These](https://github.com/NewTec-GmbH/esp32-can-iot/tree/master/Coding/fw/lib/CAN/examples) examples work. Sender and receiver. That way you can be sure your controller and tranceiver work properly
- Do you have you two 120 Ohm terminating resistors?
- Are CTX and CRX correctly and securely connected to the ESP32?
- Do you have more than one CAN Node on your Bus? If the ESP32 is alone, then it will fail on transmit
- Check your controller is not on listen-only mode
- Erase the Flash memory of the ESP32 and upload the firmware again

If after all of these, it still does not work, then we can continue looking for problems in this project.

Slenkis, 2023-01-28:
WARNING: my vp230 transiver may be damaged and packets listening only...

I have two 120 Ohm terminating resistors. Controllers in normal mode. I erased the memory on the esp32.
[This sketch](https://github.com/Seeed-Studio/Seeed_Arduino_CAN/tree/master/examples/canbus-monitor) is uploaded to arduino uno. Works fine! Tested with car bus.

### From [arduino uno + mcp2515] to [esp32 + vp230]:
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

### From [esp32 + vp230] to [arduino uno + mcp2515]:
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

### From [ELM327] to [arduino uno + mcp2515] & [esp32 + vp230]:
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

gabryelreyes, 2023-01-29:
Please check the Sender and receiver examples mentioned above. that way you can know if the tranceiver is damaged.
Also Check [this](https://github.com/sandeepmistry/arduino-CAN/issues/75) is not your case.

Slenkis, 2023-01-30:
## Please, add fix from this [PR](https://github.com/sandeepmistry/arduino-CAN/pull/97/) to your library.
### ESP32 + vp230 with this fix stable listens to packets from can bus devices.
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

### ESP32 + vp230 does not send packets to bus. Also I tried to use this [PR](https://github.com/sandeepmistry/arduino-CAN/pull/97/), but but the packets were not sent to the bus.
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

gabryelreyes, 2023-02-03:
The library is done in such a way, that you can implement your own CANAdapter according to your needs/controller/tranceiver. You can delete the CAN library provided and write your own CANAdapter using the library that works for you at best. You only have to implement the functions declared in CANInterface.h

Closed 2023-01-23.

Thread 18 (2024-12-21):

Problems after boot

Laimgss, 2024-12-21:
« [    42][E][Pref[    44][E][Preferences.cpp:483] getString(): nvs_get_str len fail: STA_SSID NOT_FOUND
[    44][E][Preferences.cpp:483] getString(): nvs_get_str len fail: STA_Password NOT_FOUND
[  2168][E][WiFiSTA.cpp:232] begin(): SSID too long or missing!
E (2147) SPIFFS: mount failed, -10025
[  2171][E][SPIFFS.cpp:89] begin(): Mounting SPIFFS failed! Error: -1

BlueAndi, 2024-12-30:
Did you flash the filesystem? Because it can't be mounted.

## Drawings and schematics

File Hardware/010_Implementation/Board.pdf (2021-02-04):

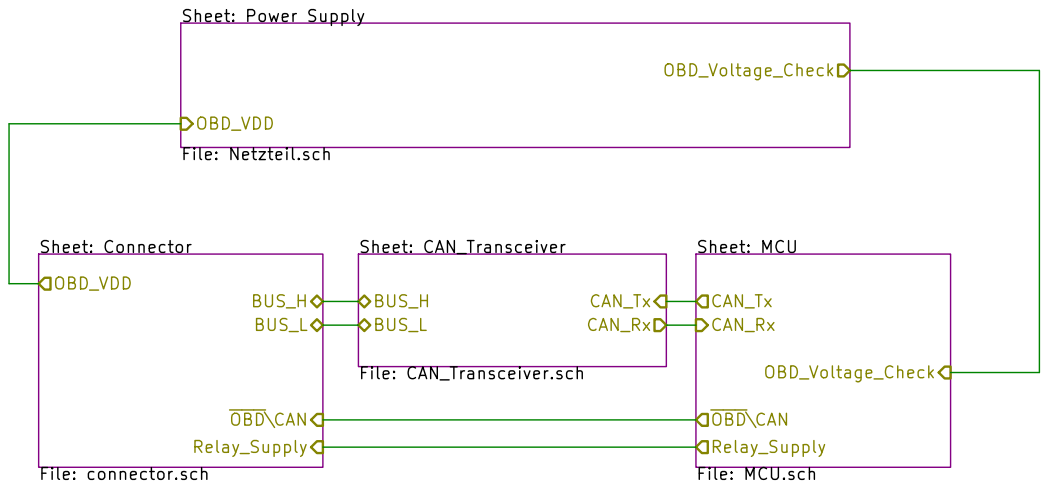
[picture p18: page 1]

Relay_Supply Sheet: Connector File: connector.sch OBD_VDD

File: MCU.sch CAN_Tx CAN_RxOBD_Voltage_Check OBD\CAN

File: Board.sch Sheet: / NewTec Gmbh. Reyes, Gabryel

Id: 1/5 Title: CAN_Bus Analyzer - Block Overview

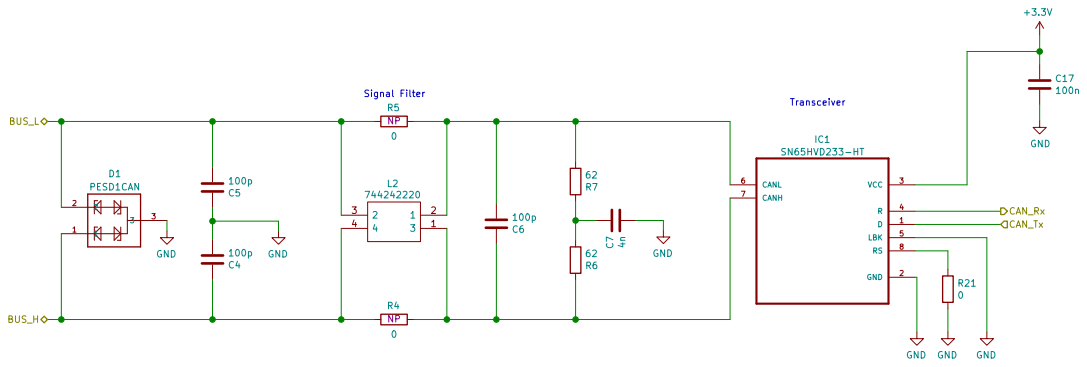
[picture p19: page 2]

Sheet: /CAN_Transceiver/ NewTec Gmbh. Reyes, Gabryel

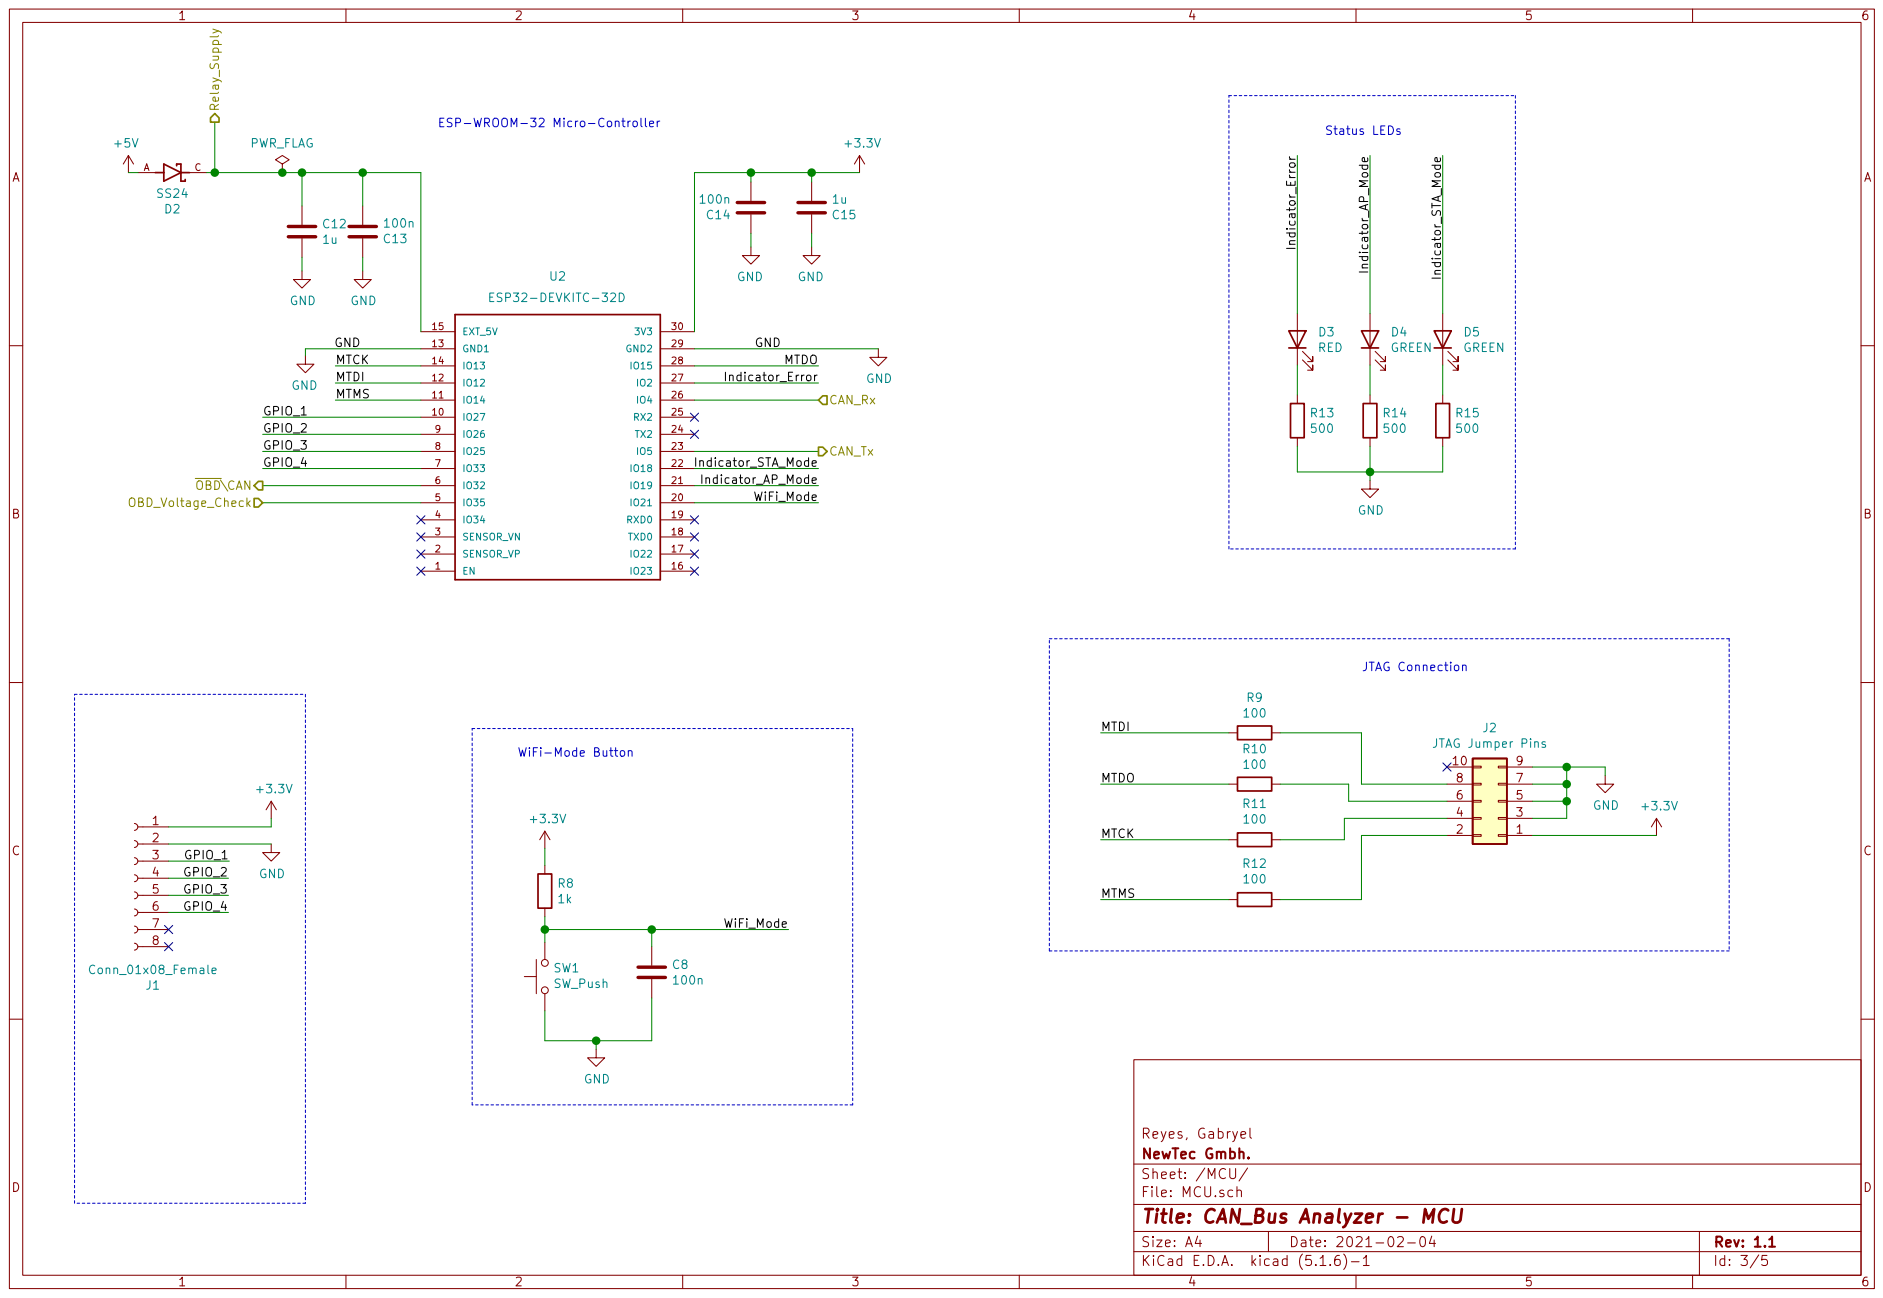
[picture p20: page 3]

File: MCU.sch Sheet: /MCU/ NewTec Gmbh. Reyes, Gabryel

Id: 3/5 Title: CAN_Bus Analyzer - MCU

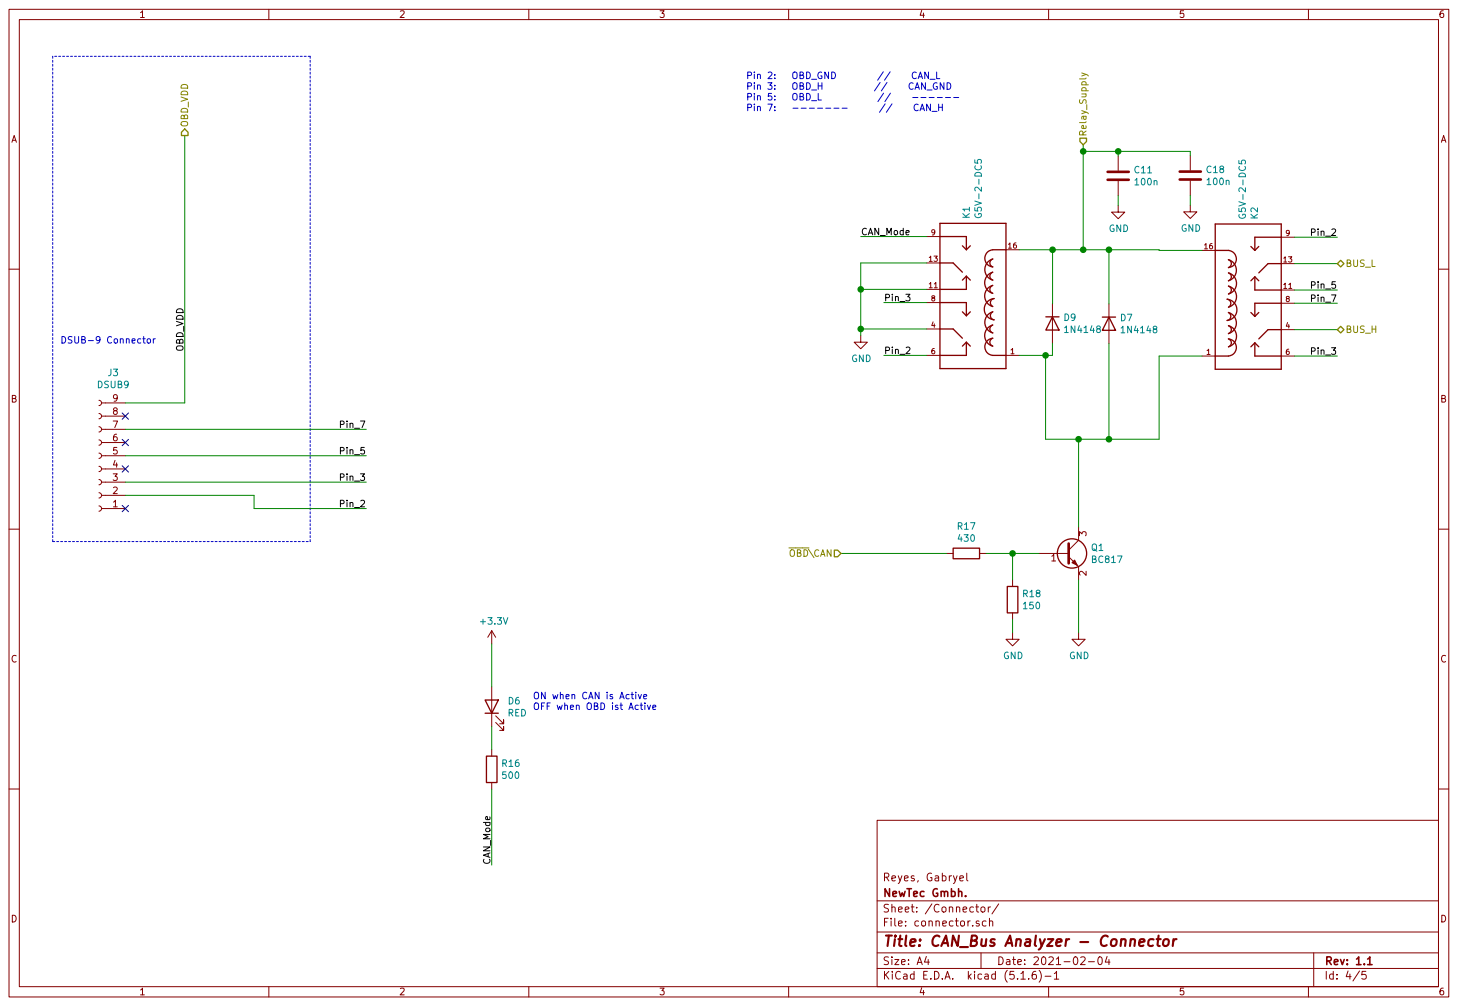
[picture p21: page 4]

Id: 4/5 Title: CAN_Bus Analyzer - Connector File: connector.sch Sheet: /Connector/ NewTec Gmbh. Reyes, Gabryel

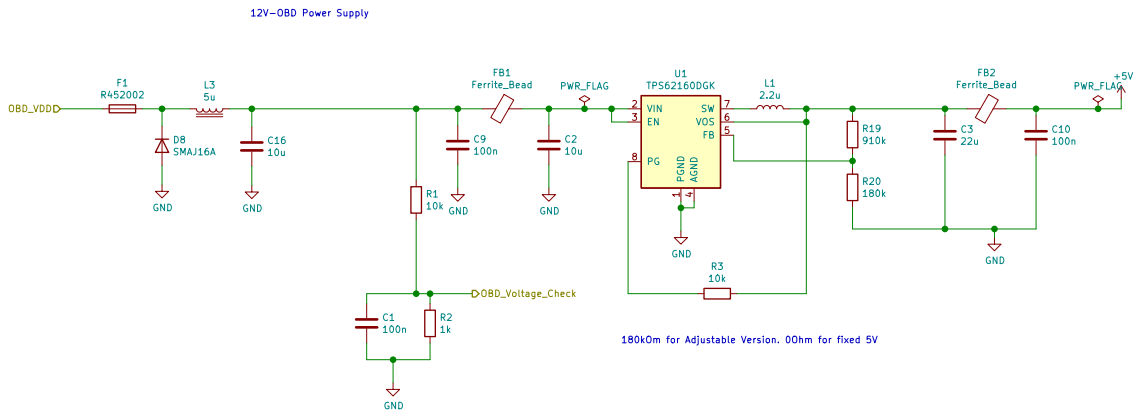
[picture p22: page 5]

4 FB 5 VOS 6 SW 7 PG 8 U1 TPS62160DGK C1

File: Netzteil.sch Sheet: /Power Supply/ NewTec Gmbh. Reyes, Gabryel GND

180kOm for Adjustable Version. 0Ohm for fixed 5V

Id: 5/5 Title: CAN_Bus Analyzer - Power Supply

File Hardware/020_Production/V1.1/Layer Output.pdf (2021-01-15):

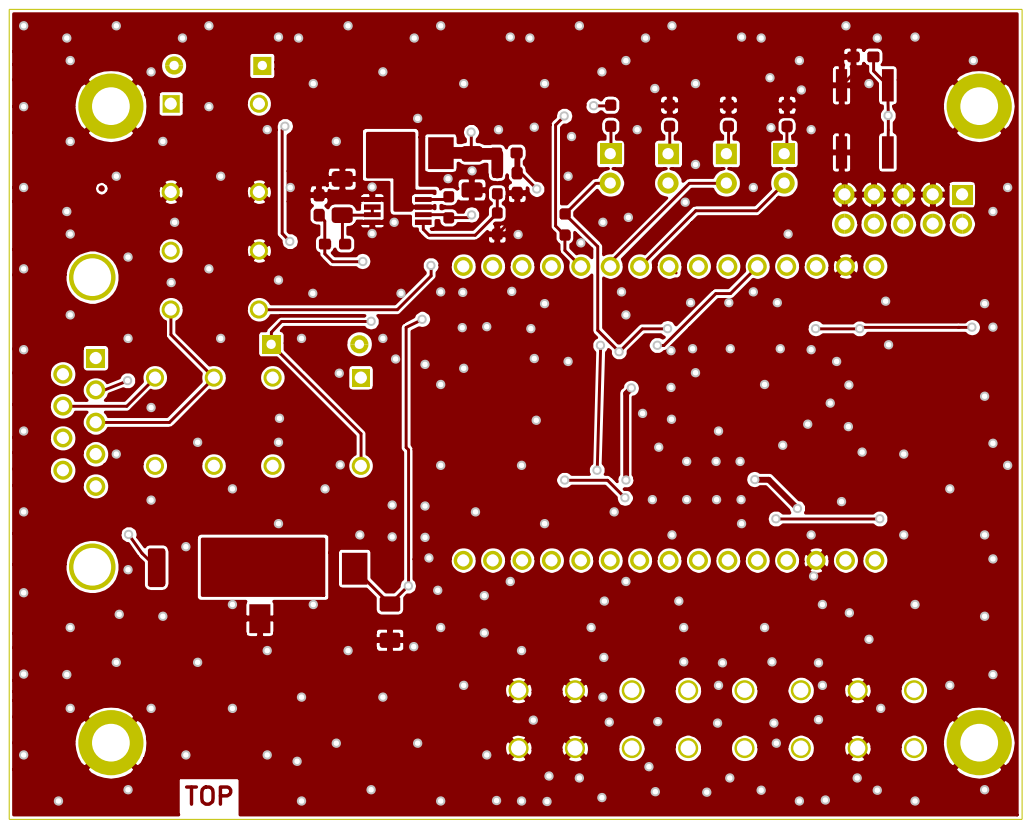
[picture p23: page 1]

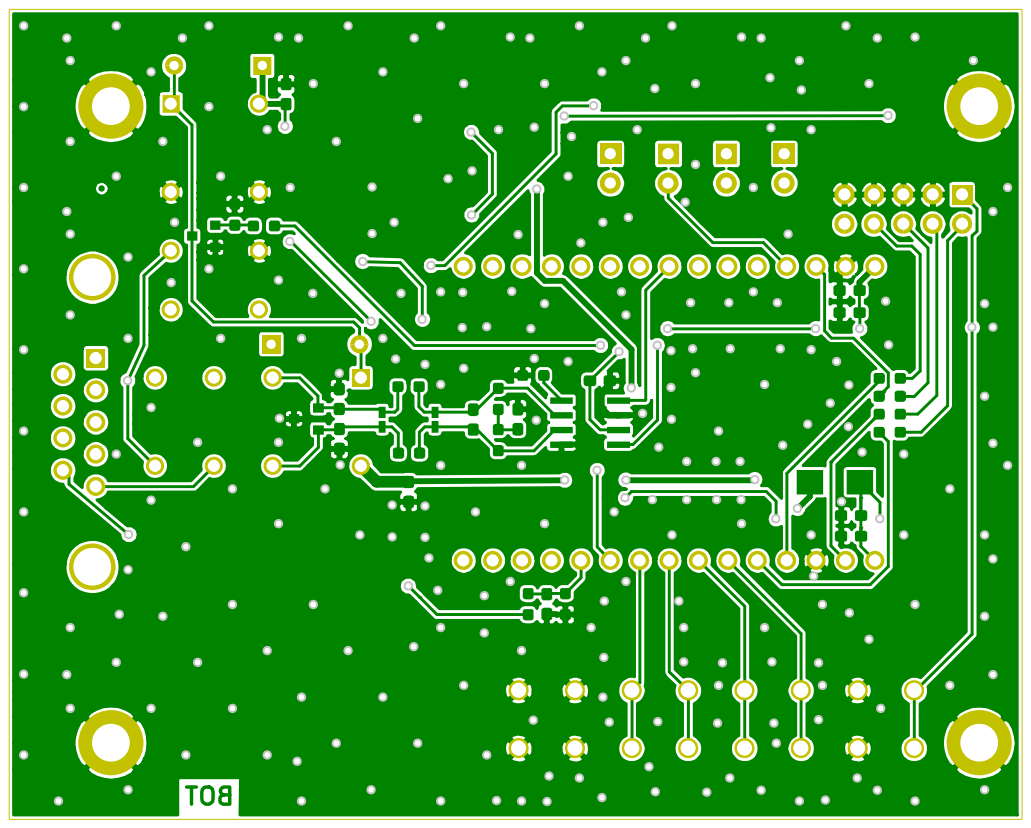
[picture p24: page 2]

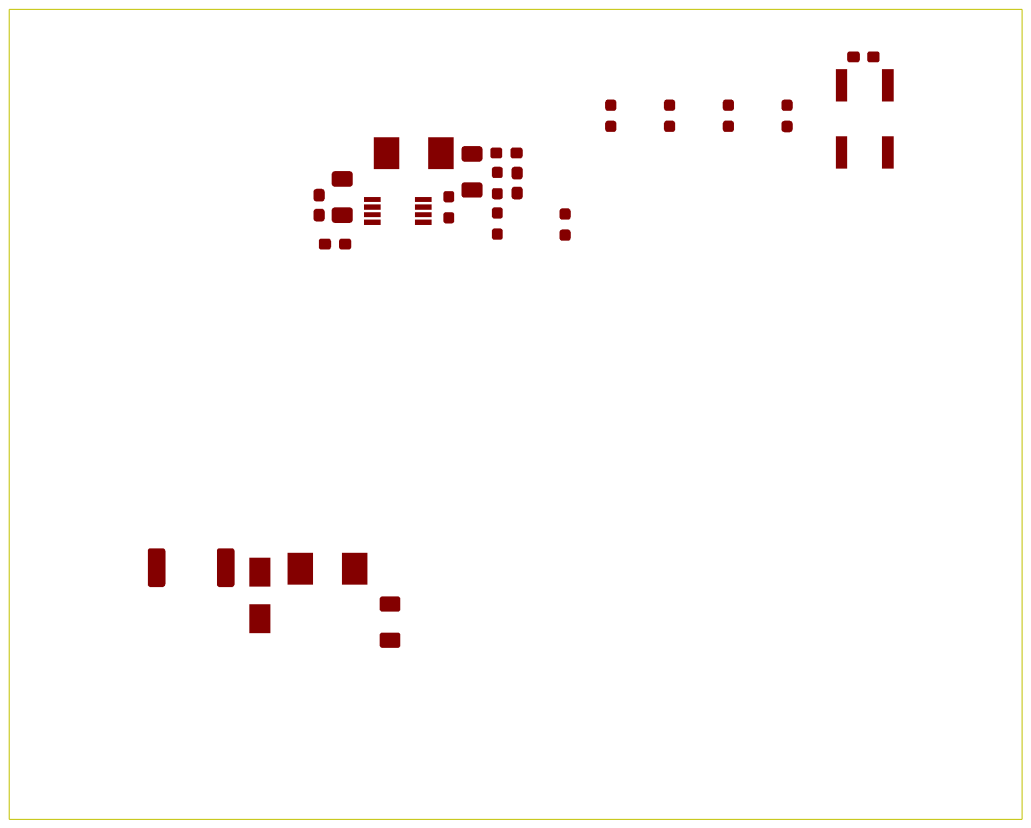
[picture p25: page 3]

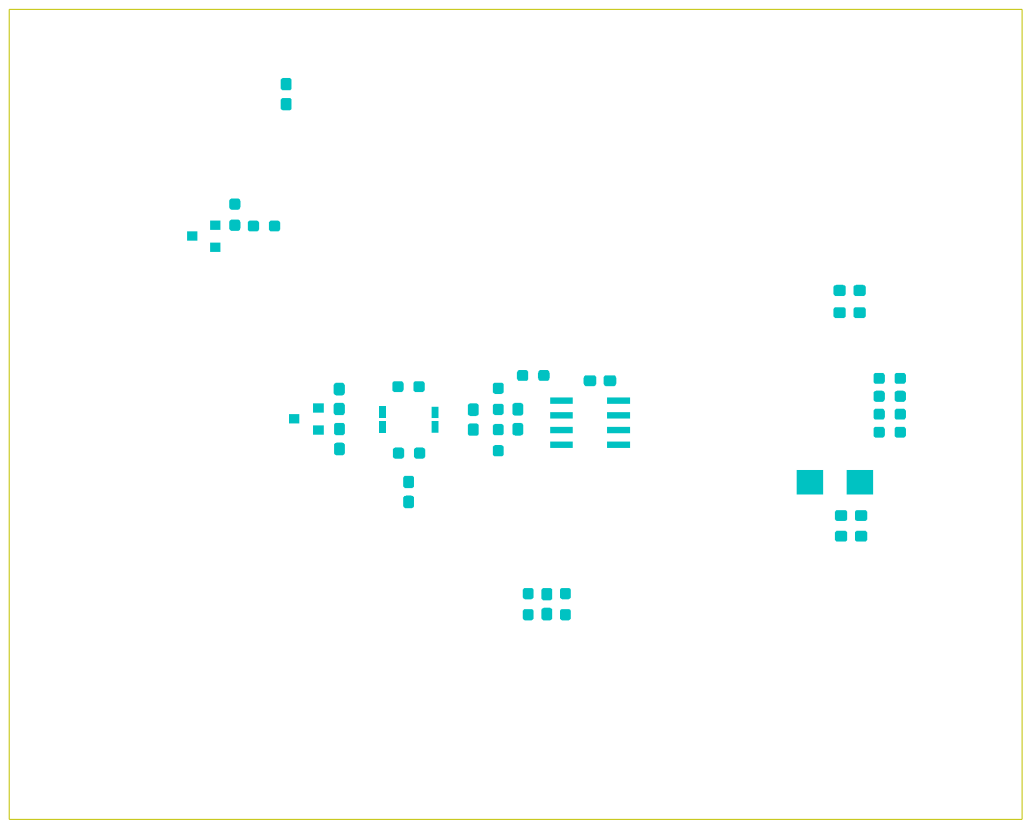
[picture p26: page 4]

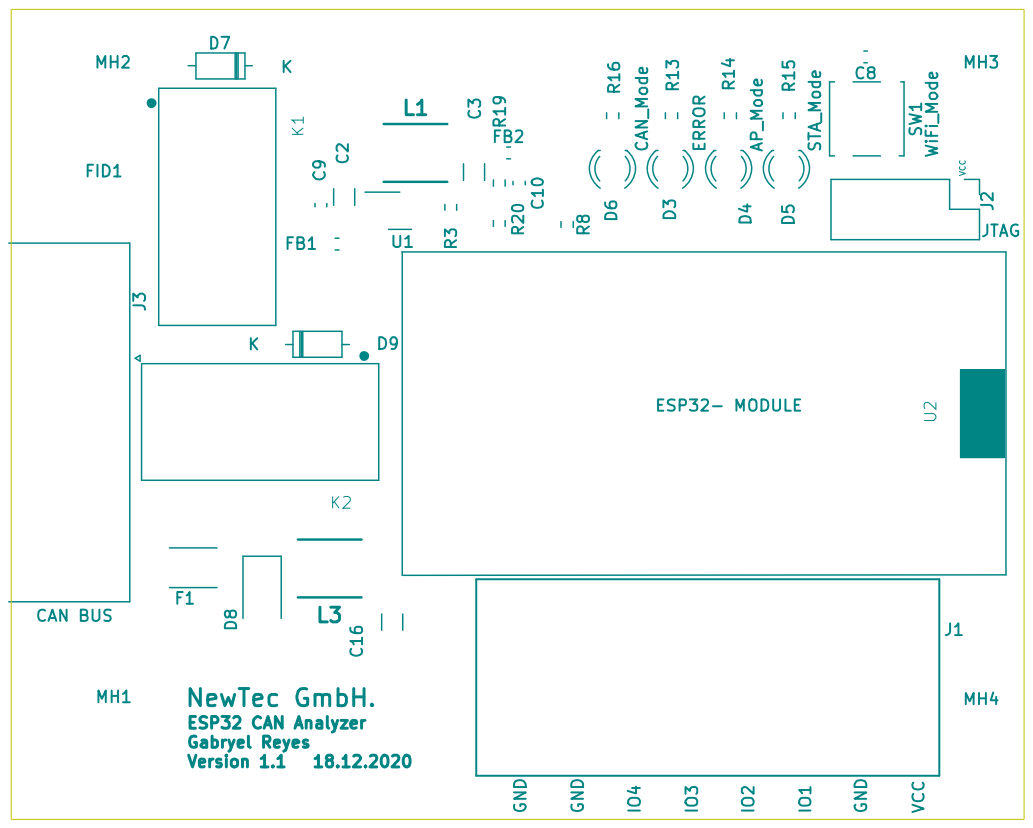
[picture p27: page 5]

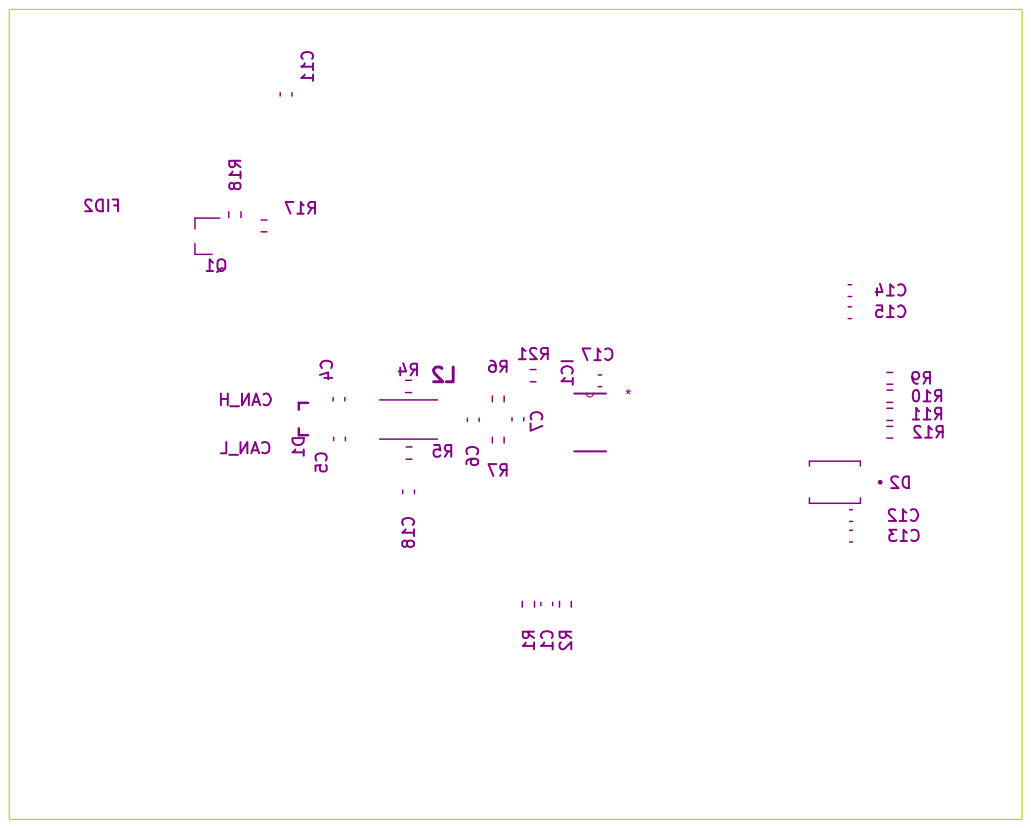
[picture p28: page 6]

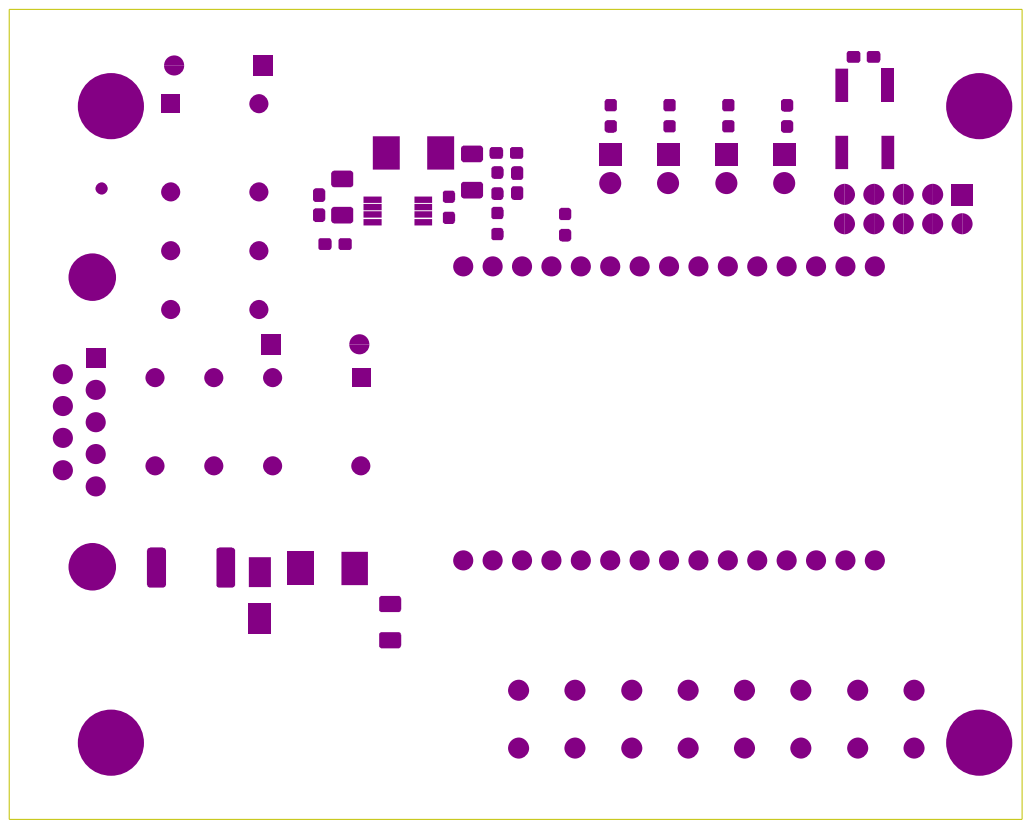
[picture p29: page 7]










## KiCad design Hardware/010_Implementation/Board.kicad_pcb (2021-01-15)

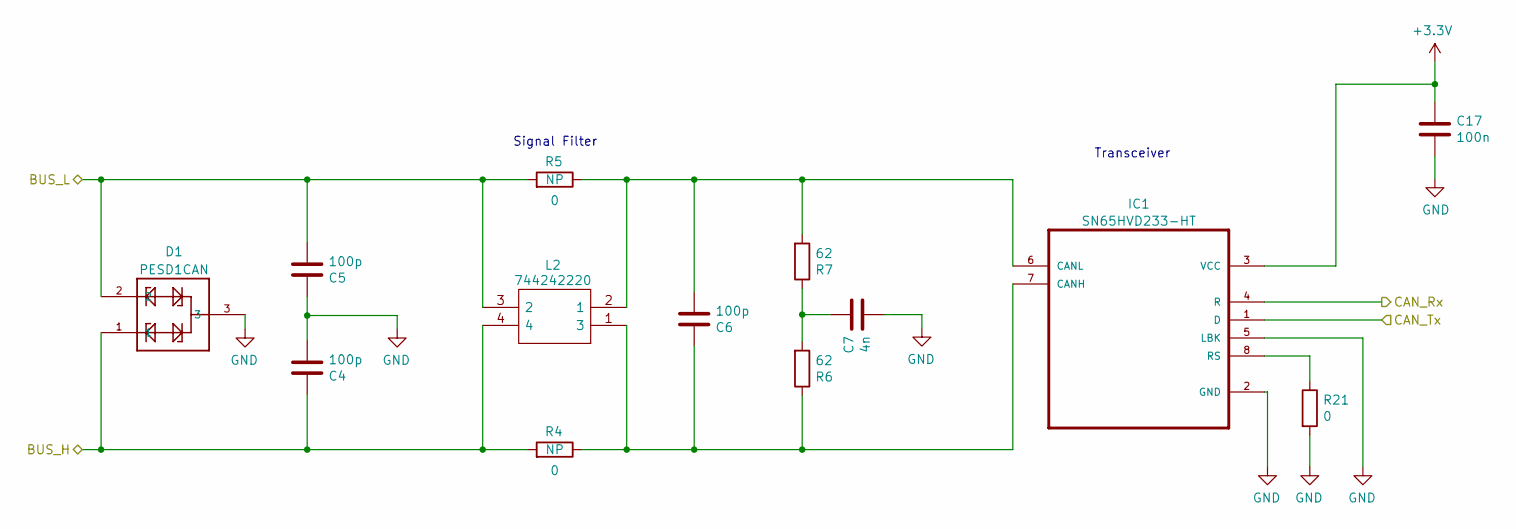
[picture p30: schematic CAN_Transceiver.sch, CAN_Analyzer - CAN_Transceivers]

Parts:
C4, C5, C6: 100p; C_0603_1608Metric_Pad1.08x0.95mm_HandSolder
C7: 4n; C_0603_1608Metric_Pad1.08x0.95mm_HandSolder
C17: 100n; C_0603_1608Metric_Pad1.08x0.95mm_HandSolder
D1: PESD1CAN; SOT23-3
IC1: SN65HVD233-HT; SOIC127P600X175
L2: 744242220; WE-SLM77; Mouser Part Number 710-744242220
R4, R5, R21: 0; R_0603_1608Metric_Pad0.98x0.95mm_HandSolder
R6, R7: 62; R_0603_1608Metric_Pad0.98x0.95mm_HandSolder

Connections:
+3V3: C17.1, IC1.3 (VCC); also elsewhere on the board
/CAN_Transceiver/BUS_H: C4.1, D1.1, L2.4, R4.2; also elsewhere on the board
/CAN_Transceiver/BUS_L: C5.2, D1.2, L2.3 (2), R5.2; also elsewhere on the board
/CAN_Transceiver/CAN_Rx: IC1.4 (R); also elsewhere on the board
/CAN_Transceiver/CAN_Tx: IC1.1 (D); also elsewhere on the board
GND: C4.2, C5.1, C7.2, C17.2, D1.3, IC1.2 (GND), IC1.5 (LBK), R21.2; also elsewhere on the board
unnamed: C6.1, IC1.7 (CANH), L2.1 (3), R4.1, R6.1
unnamed: C6.2, IC1.6 (CANL), L2.2 (1), R5.1, R7.2
unnamed: C7.1, R6.2, R7.1
unnamed: IC1.8 (RS), R21.1

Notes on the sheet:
Transceiver
Signal Filter

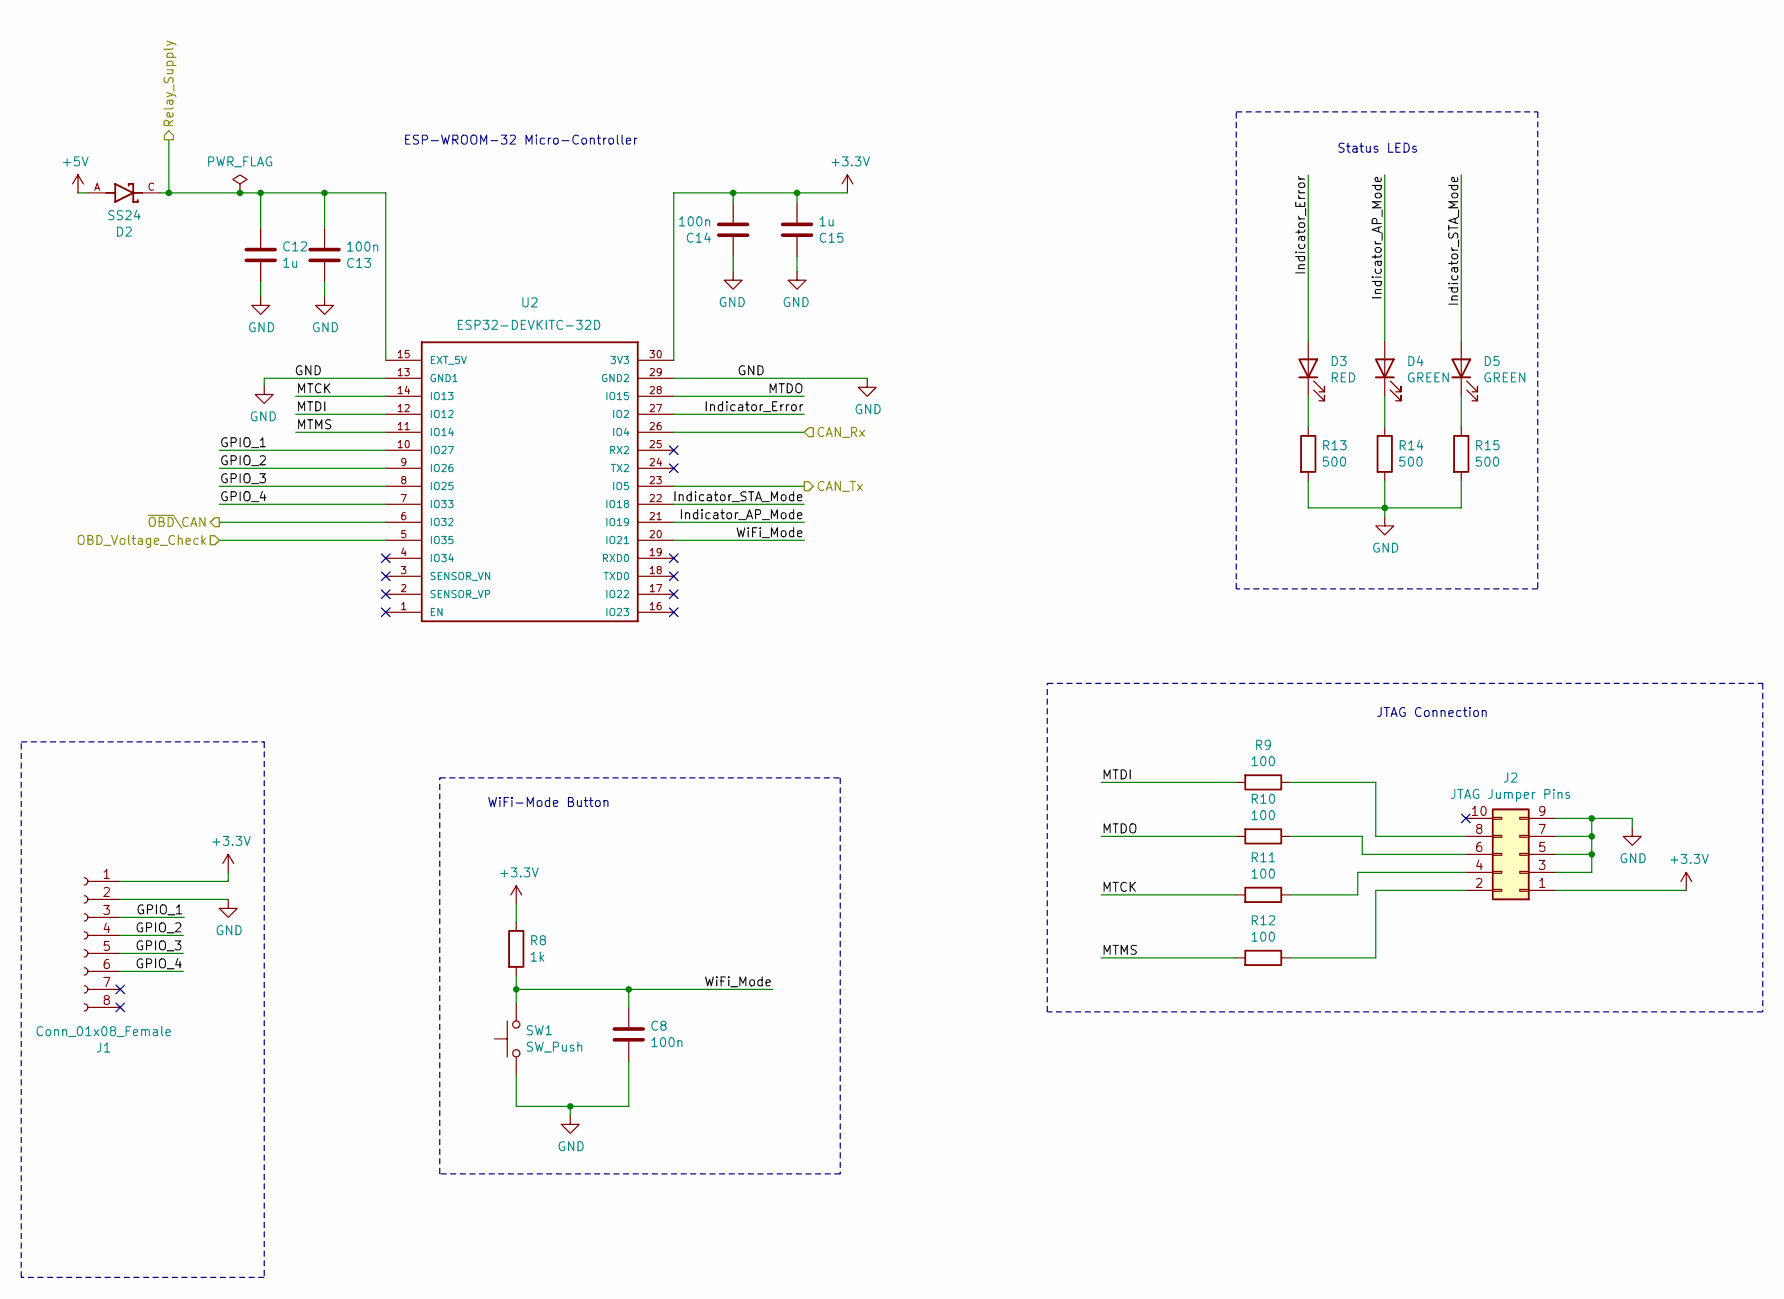
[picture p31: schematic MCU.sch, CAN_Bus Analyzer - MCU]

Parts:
C8, C13, C14: 100n; C_0603_1608Metric_Pad1.08x0.95mm_HandSolder
C12, C15: 1u; C_0603_1608Metric_Pad1.08x0.95mm_HandSolder
D2: SS24; DIOM5336X265N
D3: RED; LED_D3.0mm
D4, D5: GREEN; LED_D3.0mm
J1: Conn_01x08_Female; AST 045-08
J2: JTAG Jumper Pins; PinHeader_2x05_P1.00mm_Vertical
R8: 1k; R_0603_1608Metric_Pad0.98x0.95mm_HandSolder
R9, R10, R11, R12: 100; R_0603_1608Metric_Pad0.98x0.95mm_HandSolder
R13, R14, R15: 500; R_0603_1608Metric_Pad0.98x0.95mm_HandSolder
SW1: SW_Push; SW_Push_1P1T_NO_CK_KSC7xxJ
U2: ESP32-DEVKITC-32D; MODULE_ESP32-DEVKITC-32D

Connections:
+3V3: C14.2, C15.2, J1.1, J2.1, R8.1, U2.30 (3V3); also elsewhere on the board
+5V: D2.A; also elsewhere on the board
/CAN_Transceiver/CAN_Rx: U2.26 (IO4); also elsewhere on the board
/CAN_Transceiver/CAN_Tx: U2.23 (IO5); also elsewhere on the board
/Connector/Relay_Supply: C12.1, C13.2, D2.C, U2.15 (EXT_5V); also elsewhere on the board
/Connector/~OBD~\CAN: U2.6 (IO32); also elsewhere on the board
/MCU/GPIO_1: J1.3, U2.10 (IO27)
/MCU/GPIO_2: J1.4, U2.9 (IO26)
/MCU/GPIO_3: J1.5, U2.8 (IO25)
/MCU/GPIO_4: J1.6, U2.7 (IO33)
/MCU/Indicator_AP_Mode: D4.2 (A), U2.21 (IO19)
/MCU/Indicator_Error: D3.2 (A), U2.27 (IO2)
/MCU/Indicator_STA_Mode: D5.2 (A), U2.22 (IO18)
/MCU/MTCK: R11.2, U2.14 (IO13)
/MCU/MTDI: R9.2, U2.12 (IO12)
/MCU/MTDO: R10.2, U2.28 (IO15)
/MCU/MTMS: R12.2, U2.11 (IO14)
/MCU/OBD_Voltage_Check: U2.5 (IO35); also elsewhere on the board
/MCU/WiFi_Mode: C8.1, R8.2, SW1.2, U2.20 (IO21)
GND: C8.2, C12.2, C13.1, C14.1, C15.1, J1.2, J1.7, J1.8, J2.3, J2.5, J2.7, J2.9, R13.2, R14.2, R15.2, SW1.1, U2.13 (GND1), U2.29 (GND2); also elsewhere on the board
unnamed: D3.1 (K), R13.1
unnamed: D4.1 (K), R14.1
unnamed: D5.1 (K), R15.1
unnamed: J2.2, R12.1
unnamed: J2.4, R11.1
unnamed: J2.6, R10.1
unnamed: J2.8, R9.1

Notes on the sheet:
ESP-WROOM-32 Micro-Controller
Status LEDs
WiFi-Mode Button
JTAG Connection

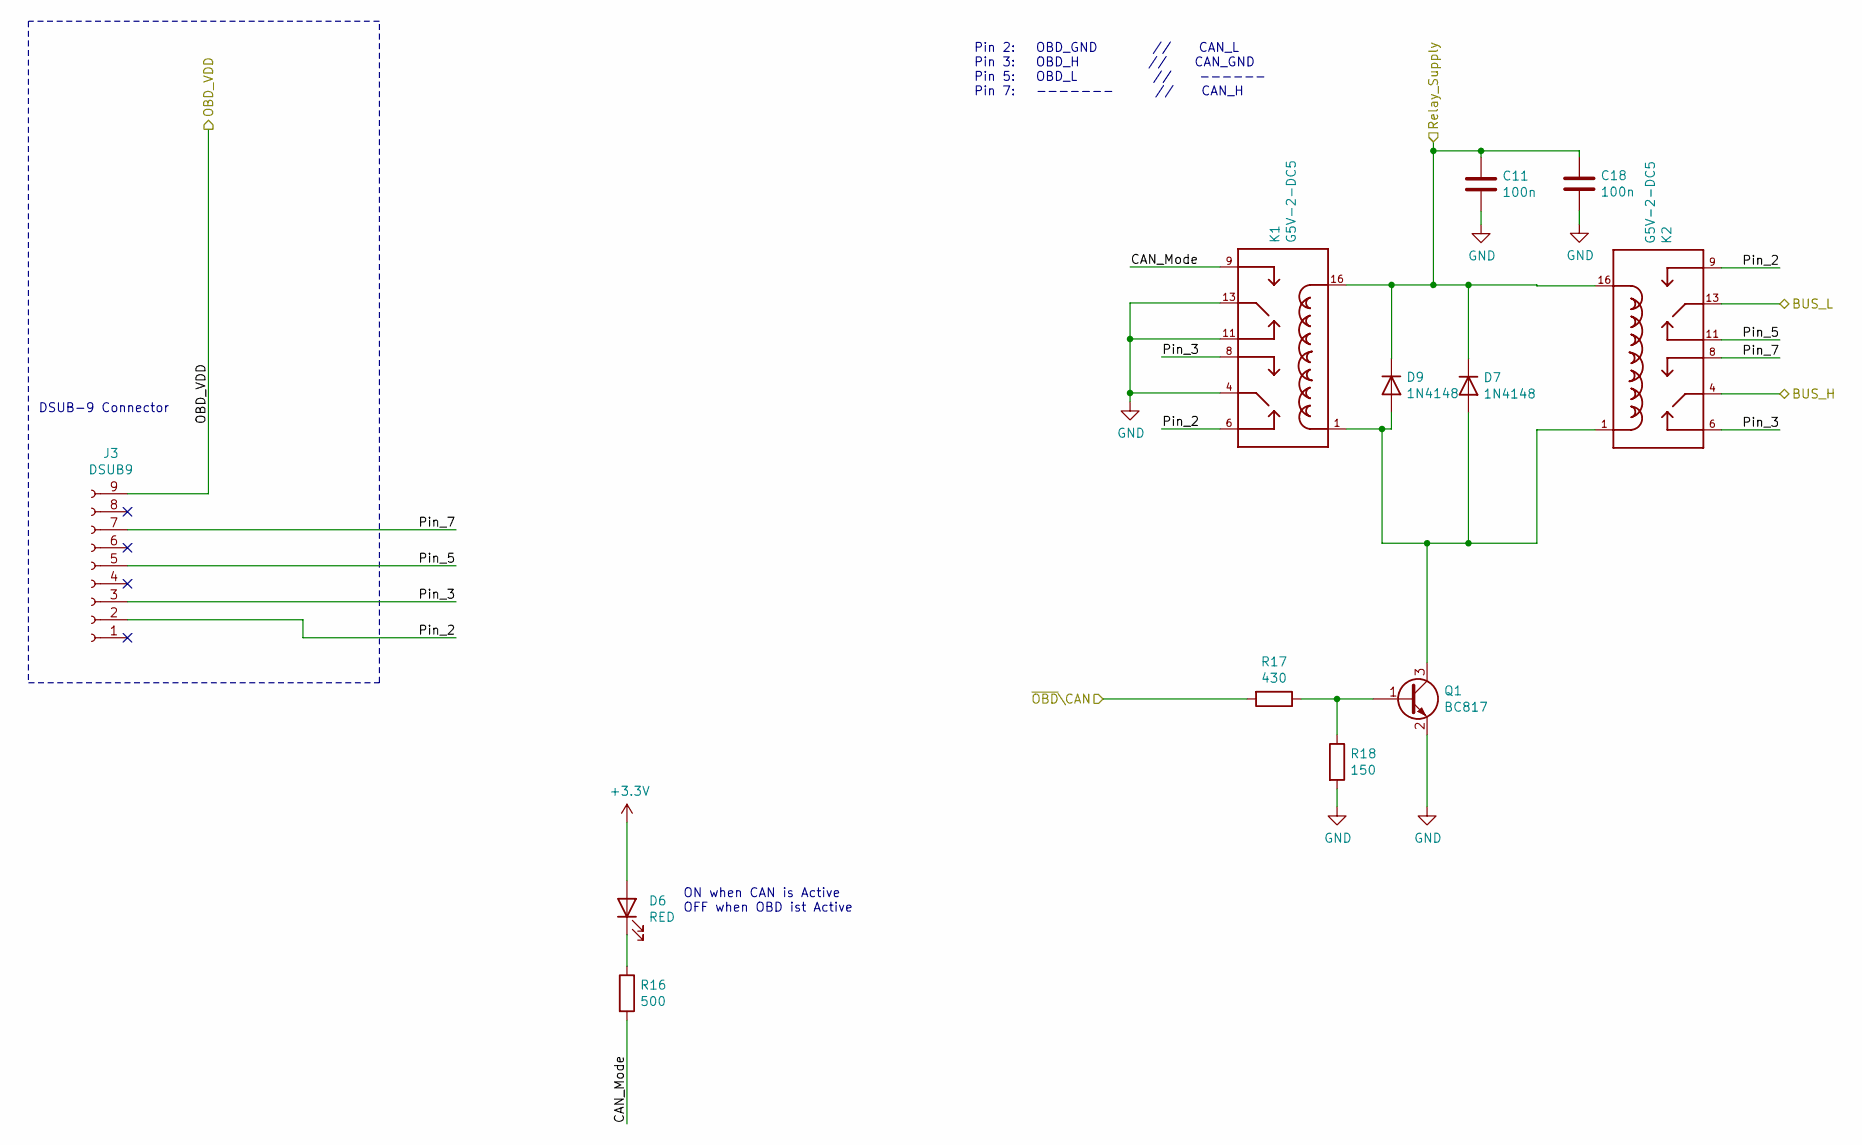
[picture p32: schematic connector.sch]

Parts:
C11, C18: 100n; C_0603_1608Metric_Pad1.08x0.95mm_HandSolder
D6: RED; LED_D3.0mm
D7, D9: 1N4148; D_DO-35_SOD27_P7.62mm_Horizontal
J3: DSUB9; DSUB-9_Male_Horizontal_P2.77x2.84mm_EdgePinOffset4.94mm_Hou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
K1, K2: G5V-2-DC5; RELAY_G5V-2-DC5
Q1: BC817; SOT-23
R16: 500; R_0603_1608Metric_Pad0.98x0.95mm_HandSolder
R17: 430; R_0603_1608Metric_Pad0.98x0.95mm_HandSolder
R18: 150; R_0603_1608Metric_Pad0.98x0.95mm_HandSolder

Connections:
+3V3: D6.2 (A); also elsewhere on the board
/CAN_Transceiver/BUS_H: K2.4; also elsewhere on the board
/CAN_Transceiver/BUS_L: K2.13; also elsewhere on the board
/Connector/CAN_Mode: K1.9, R16.2
/Connector/OBD_VDD: J3.9; also elsewhere on the board
/Connector/Pin_2: J3.2, K1.6, K2.9
/Connector/Pin_3: J3.3, K1.8, K2.6
/Connector/Pin_5: J3.5, K2.11
/Connector/Pin_7: J3.7, K2.8
/Connector/Relay_Supply: C11.1, C18.1, D7.1 (K), D9.1 (K), K1.16, K2.16; also elsewhere on the board
/Connector/~OBD~\CAN: R17.2; also elsewhere on the board
GND: C11.2, C18.2, K1.4, K1.11, K1.13, Q1.2 (E), R18.2; also elsewhere on the board
unnamed: D6.1 (K), R16.1
unnamed: D7.2 (A), D9.2 (A), K1.1, K2.1, Q1.3 (C)
unnamed: Q1.1 (B), R17.1, R18.1

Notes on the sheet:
DSUB-9 Connector
Pin 2: OBD_GND // CAN_L Pin 3: OBD_H // CAN_GND Pin 5: OBD_L // ------ Pin 7: ------- // CAN_H
ON when CAN is Active OFF when OBD ist Active

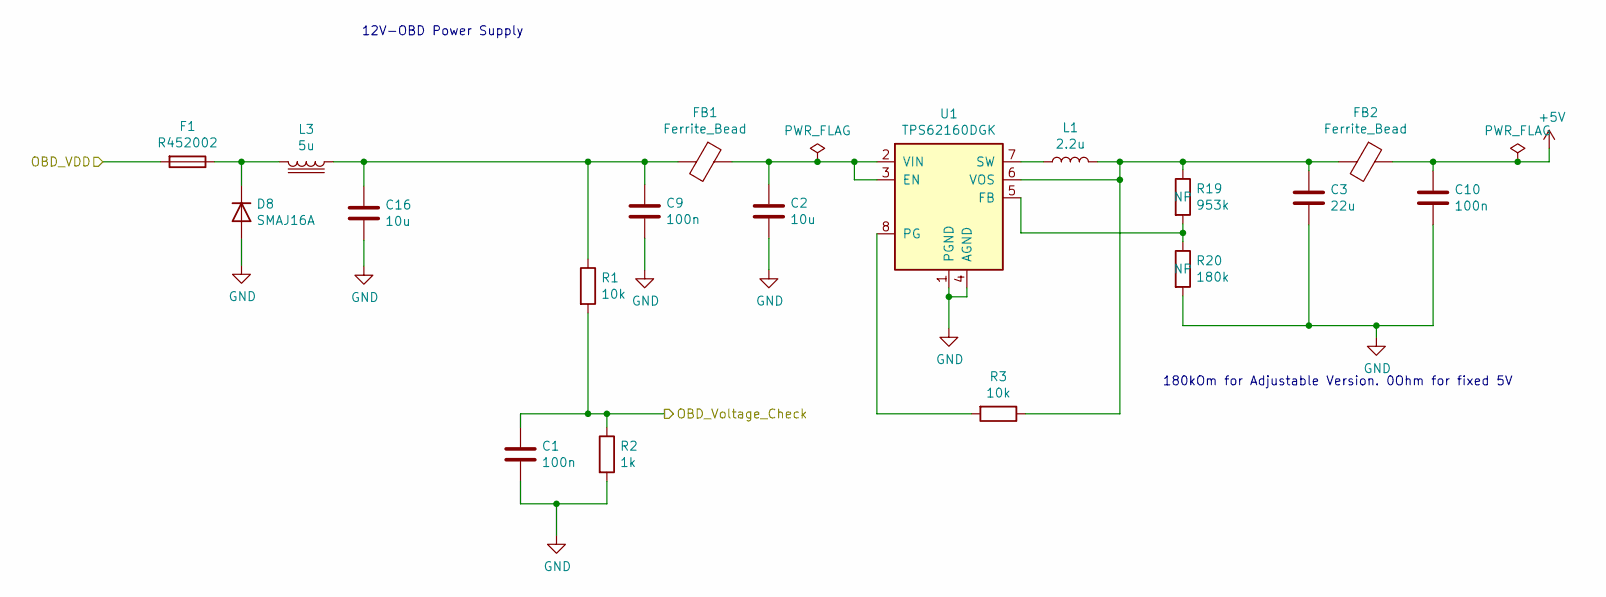
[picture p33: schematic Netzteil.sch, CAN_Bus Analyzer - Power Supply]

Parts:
C1, C9, C10: 100n; C_0603_1608Metric_Pad1.08x0.95mm_HandSolder
C2, C16: 10u; C_1206_3216Metric_Pad1.33x1.80mm_HandSolder
C3: 22u; C_1206_3216Metric_Pad1.33x1.80mm_HandSolder
D8: SMAJ16A; D_SMA
F1: R452002; Fuse_2512_6332Metric_Pad1.52x3.35mm_HandSolder
FB1, FB2: Ferrite_Bead; L_0603_1608Metric_Pad1.05x0.95mm_HandSolder
L1: 2.2u; INDPM5550X300N
L3: 5u; INDPM5550X300N
R1, R3: 10k; R_0603_1608Metric_Pad0.98x0.95mm_HandSolder
R2: 1k; R_0603_1608Metric_Pad0.98x0.95mm_HandSolder
R19: 953k; R_0603_1608Metric_Pad0.98x0.95mm_HandSolder
R20: 180k; R_0603_1608Metric_Pad0.98x0.95mm_HandSolder
U1: TPS62160DGK; VSSOP-8_3.0x3.0mm_P0.65mm

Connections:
+5V: C10.1, FB2.1; also elsewhere on the board
/Connector/OBD_VDD: F1.2; also elsewhere on the board
/MCU/OBD_Voltage_Check: C1.1, R1.2, R2.1; also elsewhere on the board
GND: C1.2, C2.2, C3.2, C9.2, C10.2, C16.2, D8.2 (A), R2.2, R20.2, U1.1 (PGND), U1.4 (AGND); also elsewhere on the board
unnamed: C2.1, FB1.1, U1.2 (VIN), U1.3 (EN)
unnamed: C3.1, FB2.2, L1.2, R3.1, R19.1, U1.6 (VOS)
unnamed: C9.1, C16.1, FB1.2, L3.1, R1.1
unnamed: D8.1 (K), F1.1, L3.2
unnamed: L1.1, U1.7 (SW)
unnamed: R3.2, U1.8 (PG)
unnamed: R19.2, R20.1, U1.5 (FB)

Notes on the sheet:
12V-OBD Power Supply
180kOm for Adjustable Version. 0Ohm for fixed 5V

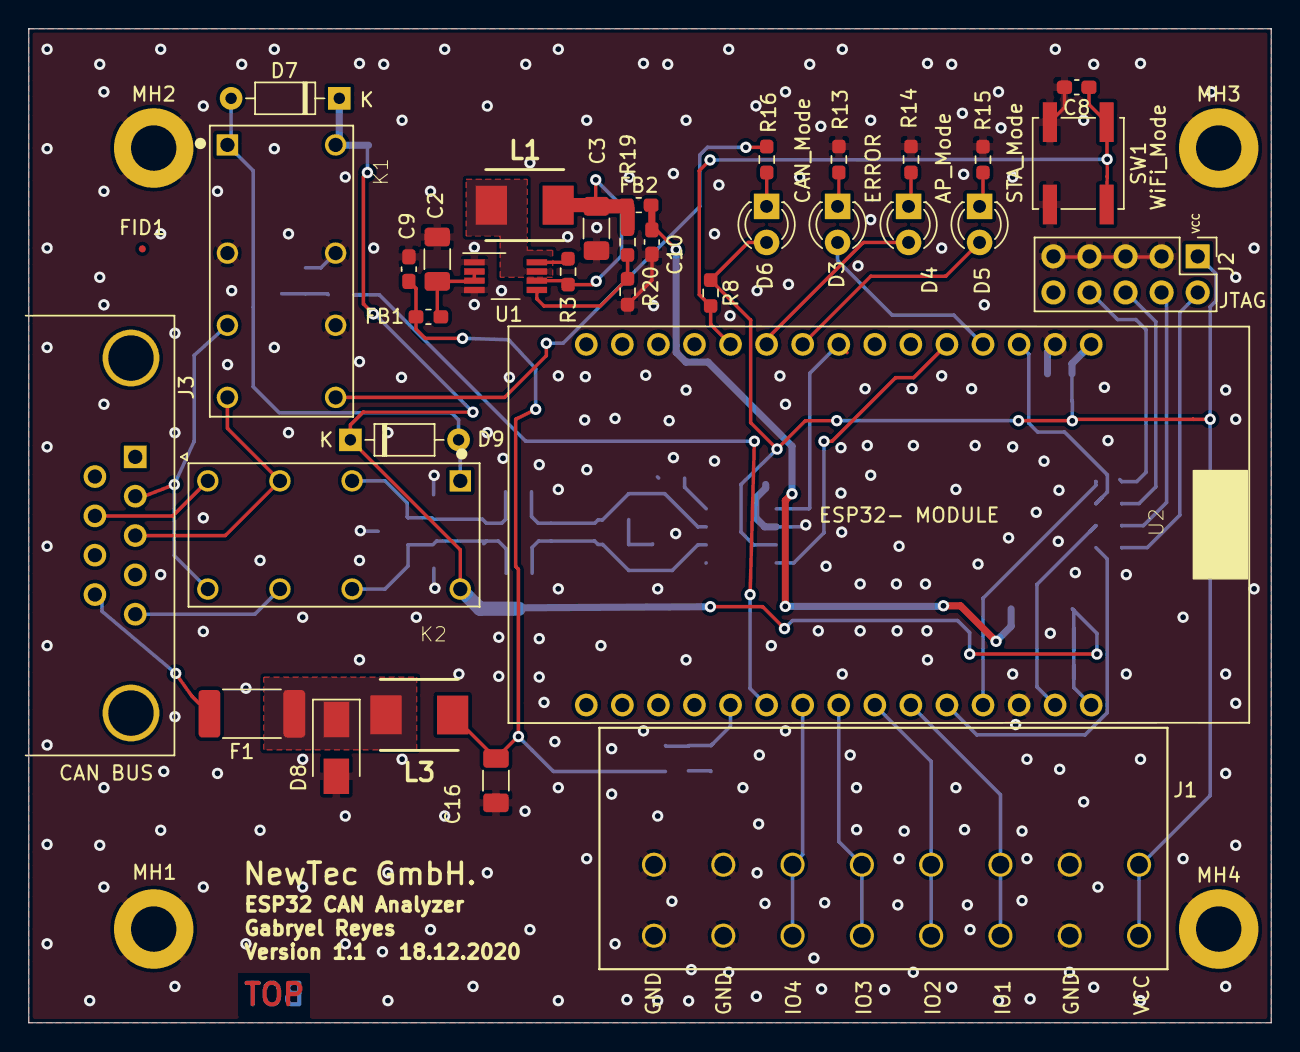
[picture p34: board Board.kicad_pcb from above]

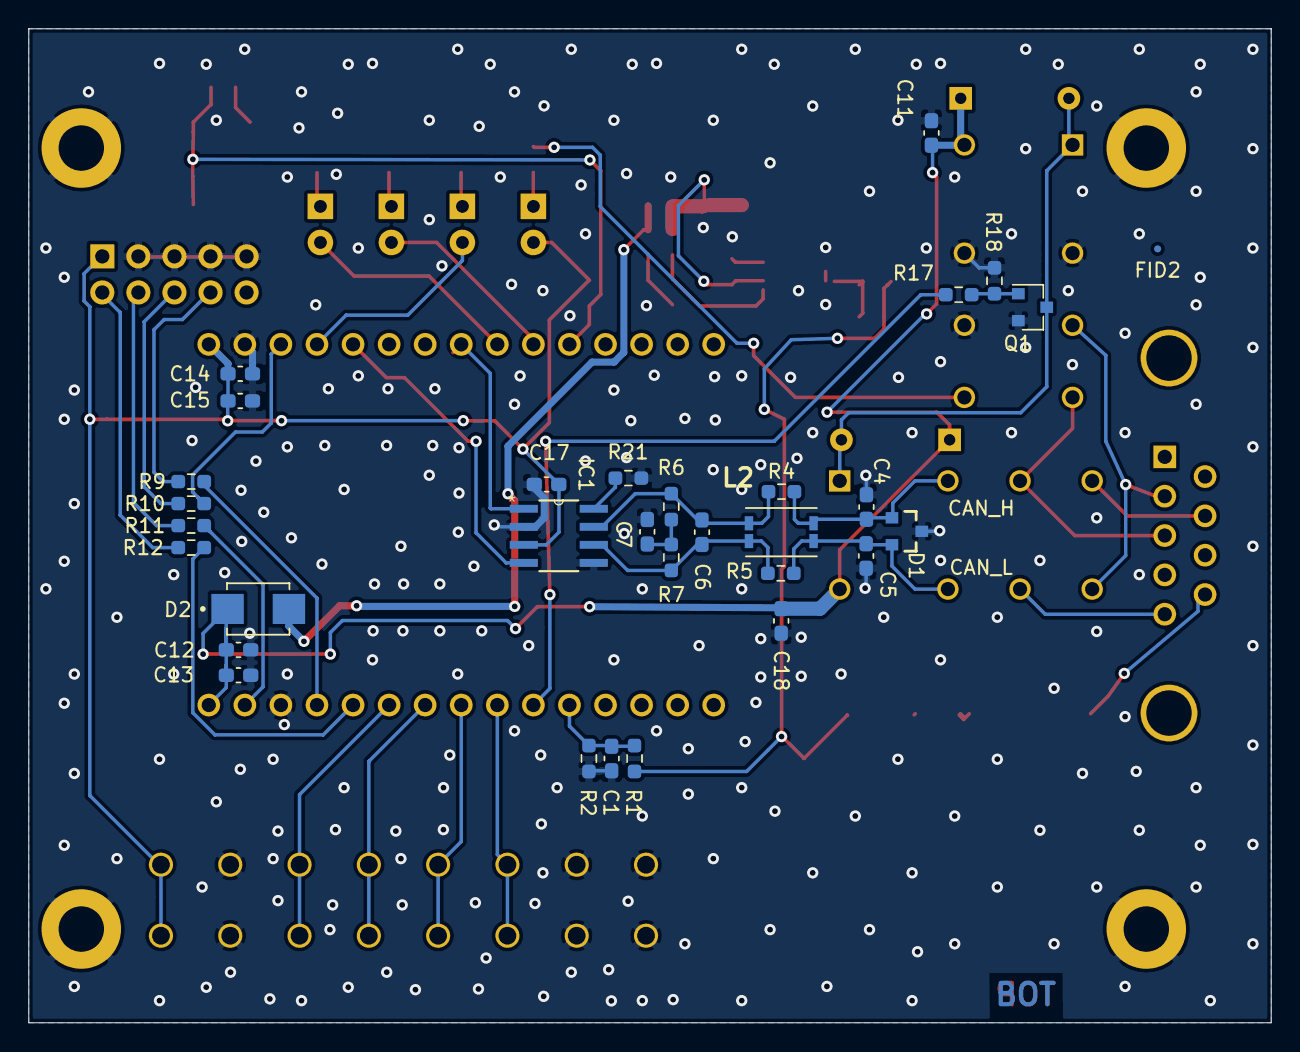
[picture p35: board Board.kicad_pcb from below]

Board: 2 copper layers, 87.5 x 70.0 mm, 70 parts (31 on the bottom side), 49 nets.

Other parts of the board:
FID1, FID2: Fiducial_0.5mm_Mask1mm
MH1, MH2, MH3, MH4: MountingHole_3.2mm_M3_DIN965_Pad

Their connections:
GND: MH1.1, MH2.1, MH3.1, MH4.1; also elsewhere on the board

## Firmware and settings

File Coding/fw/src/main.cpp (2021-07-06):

/***************************************************************************************************
BSD 3-Clause License


Copyright (c) 2020-2021, NewTec GmbH - www.newtec.de
All rights reserved.


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

1. Redistributions of source code must retain the above copyright notice, this
   list of conditions and the following disclaimer.


2. Redistributions in binary form must reproduce the above copyright notice,
   this list of conditions and the following disclaimer in the documentation
   and/or other materials provided with the distribution.


3. Neither the name of the copyright holder nor the names of its
   contributors may be used to endorse or promote products derived from
   this software without specific prior written permission.


THIS SOFTWARE IS PROVIDED BY THE COPYRIGHT HOLDERS AND CONTRIBUTORS "AS IS"
AND ANY EXPRESS OR IMPLIED WARRANTIES, INCLUDING, BUT NOT LIMITED TO, THE
IMPLIED WARRANTIES OF MERCHANTABILITY AND FITNESS FOR A PARTICULAR PURPOSE ARE
DISCLAIMED. IN NO EVENT SHALL THE COPYRIGHT HOLDER OR CONTRIBUTORS BE LIABLE
FOR ANY DIRECT, INDIRECT, INCIDENTAL, SPECIAL, EXEMPLARY, OR CONSEQUENTIAL
DAMAGES (INCLUDING, BUT NOT LIMITED TO, PROCUREMENT OF SUBSTITUTE GOODS OR
SERVICES; LOSS OF USE, DATA, OR PROFITS; OR BUSINESS INTERRUPTION) HOWEVER
CAUSED AND ON ANY THEORY OF LIABILITY, WHETHER IN CONTRACT, STRICT LIABILITY,
OR TORT (INCLUDING NEGLIGENCE OR OTHERWISE) ARISING IN ANY WAY OUT OF THE USE
OF THIS SOFTWARE, EVEN IF ADVISED OF THE POSSIBILITY OF SUCH DAMAGE.
***************************************************************************************************/
/**
@addtogroup Application
@{
@file       main.cpp

Main Application

* @}
***************************************************************************************************/
/* INCLUDES ***************************************************************************************/
#include <Arduino.h>
#include "Lawicel.h"
#include "SerialAdapter.h"
#include "CANAdapter.h"
#include "NVMAdapter.h"
#include "WebSocketAdapter.h"
#include "Board.h"
#include "WLAN.h"

/* CONSTANTS **************************************************************************************/

/* MACROS *****************************************************************************************/

/* TYPES ******************************************************************************************/

/* PROTOTYPES *************************************************************************************/

/* VARIABLES **************************************************************************************/

static SerialAdapter gSerialAdapter; /**< Serial Adapter Instance */
static CANAdapter gSja1000Adapter;   /**< CAN Adapter Instance */
static NVMAdapter gFlashAdapter;     /**< NVM Adapter Instance */
static WebSocketAdapter gWsadapter;  /**< WebSocket Adapter Instance */

/** Lawicel Protocol Instance */
static Lawicel gProtocolLawicel(gWsadapter, gSja1000Adapter, gFlashAdapter);

static uint32_t gLastSend = 0;  /**< Timestamp of last sent WebSocket Buffer */
static uint32_t gWaitTime = 50; /**< Delay between WebSocket Buffer send */

/* PUBLIC METHODES ********************************************************************************/

/**************************************************************************************************/

/**
 *  Initialization of Application
 */
void setup()
{
    Board::init();
    if (!gProtocolLawicel.begin())
    {
        Board::haltSystem();
    }
    else
    {
        Serial.println(wlan::getIPAddress());
    }
}

/**************************************************************************************************/

/**
 *  Application Loop
 */
void loop()
{
    if (!wlan::getAP_MODE())
    {
        if (!gProtocolLawicel.executeCycle())
        {
            Board::blinkError(250);
        }
        if (!wlan::checkConnection())
        {
            Board::haltSystem();
        }
    }
    if (ESPServer::isRestartRequested())
    {
        Board::reset();
    }

    if (millis() - gLastSend > gWaitTime)
    {
        gLastSend = millis();
        websocket::sendBuffer();
    }
}

/* PROTECTED METHODES *****************************************************************************/

/* PRIVATE METHODES *******************************************************************************/

/* EXTERNAL FUNCTIONS *****************************************************************************/

/* INTERNAL FUNCTIONS *****************************************************************************/

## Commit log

2020-08-03 FW: Add PlatformIO skeleton for Expressif ESP32
    - create Coding/fw folder holding firmware source tree
    - create default arduino environment for Espressif ESP32
2020-09-28 Hardware Data uploaded
    [Board.dsn, Board.kicad_pcb, Board.sch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]
2020-10-01 Switch implemented for individual commands
2020-10-01 Bug fixed in enum BUS_STATE, which defaulted the switches instead of going into the cases
2020-10-01 CMD_Close implemented and tested. Implementation and improvemente of texts to improve debugging through Serial monitor. Changed order of plausibility checks of commands: First checks if command is co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
    [main.cpp]
2020-10-02 IdDecode function changed to decode both std and ext frames CMD_Tx_Ext() started
2020-10-05 Structs for Frames and Commands
2020-10-05 Transmision of RTR Frames implemented
2020-10-05 Finished implementing "receive Command" Implemented Filtering and Set_Acn() Fixed return values from most CMD functions
2020-10-06 timestamp toggle implemented. Code cleaned Serial.print() functions deleted as a handler is used
2020-10-06 Changes to Schematic. Button, LEDs and Power Flags
    [CAN_Transceiver.sch, MCU.sch, Netzteil.sch]
2020-10-08 Interface Constructor and Destructor Bug fixed PRoblem with the Declaration/Definition of these methods
    [main.cpp]
2020-10-08 NVMAdapter und NVMInterface implementiert
2020-10-08 Fixed NVMAdapter declaration: Interface was not included
    [main.cpp]
2020-10-09 Initial Testing Implemented different print methods for SerialInterface
2020-10-12 Fixed Single Polling. Error with frame pointer Fixed by making return type a Frame instead of int
2020-10-13 Fixed constructor of Frame. Before the Data Buffer was created depending on the DLC. Now all frames have 8 Data positions initialized to 0. Sending/receiving depends on the DLC
2020-10-13 tx_std Tested. test_can_adapter fixed to clear output frame after each test
2020-10-13 Mem allocation for tx frames deleted (as per last Commit)
2020-10-14 Tested Filters
2020-10-14 Data from Frame fixed. Faulty method in Library used
2020-10-15 Deleted input message debug-printing
2020-10-15 Fixed Terminator CR in outputSerial. Deleted Debug Serial Messages
    [main.cpp]
2020-10-15 Doxygen First Build. Fixed Headers
    [main.cpp]
2020-10-21 Fixed Coding Style for Lawicel.h and CAN adapters. Improved implementation of pollSingle; setFilterMode. Changed Pointer to Reference in LAwicel Constructor
    [main.cpp]
2020-10-26 charToByte as implemented as Switch
2020-10-26 Deleted Scope Brackets from switch case statements
2020-10-27 Added ESP32-DEVKit Schematic
2020-10-28 Send frame fixed: send only when success starting frame
2020-10-28 Changed Filter input for struct. This restricts the input for more reliability
2020-10-29 Updated Schematic. Fixed Connection to Ground to prevent Software Bugs
    [MCU.sch, Netzteil.sch]
2020-10-29 Changed return types for error handling to bool. Implemented auto-connect as STA in begin(). restart() method in main application.
    [main.cpp]
2020-10-30 Added IO and Board Classes
2020-11-02 Fixed Board to NewTec Coding Style. Board included in main.cpp
    [main.cpp]
2020-11-03 Modified Board Schematic. Optimized supply and switching system through Software
    [Board.dsn, Board.kicad_pcb, Board.sch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]
2020-11-03 Added Schotlly Diode, PDF and autorouted Vias
    [Board.kicad_pcb]
2020-11-03 Implemented Debouncing for WiFi Mode button
2020-11-03 Error handling in Main restarts the system. Fixed restart when NVM Entry is empty, as this is valid
    [main.cpp]
2020-11-03 Added Missing 5V marker
    [Board.sch, MCU.sch, Netzteil.sch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]
2020-11-09 PCB Updated
    [Board.dsn, Board.kicad_pcb, CAN_Transceiver.sch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]
2020-11-09 Board version 4
    [Board.dsn, Board.kicad_pcb, CAN_Transceiver.sch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]
2020-11-10 Board version 4.1
    [Board.kicad_pcb, CAN_Transceiver.sch, MCU.sch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]
2020-11-11 Board Version 4.2
    [Board.sch, CAN_Transceiver.sch, MCU.sch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]
2020-11-12 Board Version 5
    [Board.csv, Board.dsn, Board.kicad_pcb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]
2020-11-12 Error LED in Main implementiert
    [main.cpp]
2020-11-23 Board Version 6
    [Board.csv, Board.dsn, Board.kicad_pcb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]
2020-11-24 Board Version 7
    [Board.dsn, Board.kicad_pcb, MCU.sch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]
2020-11-24 Added Anchor points to PCB
    [BOM.xlsx, Board.kicad_pcb]
2020-11-24 Moved Pi-Filter to the top section. Added alignment marks on the back layer.
    [BOM.xlsx, Board.csv, Board.dsn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]
2020-11-25 Board version 8 with gerber files
    [Board-B_Cu.gbr, Board-B_Mask.gbr, Board-B_Paste.gbr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]
2020-11-26 Updated BOM
    [BOM.xlsx]
2020-11-27 Board Version 1.0 Review 3
    [BOM.xlsx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]
2020-11-30 Cleaned Board export files
    [Board-NPTH.drl, Board-PTH.drl, Board.drl]
2020-12-01 Halt function implemented. Resstart called from Board
2020-12-01 MIT Licence for IO and Board Classes
2020-12-01 Board Version 1.0 Review 4
    [Board-B_Cu.gbr, Board-B_Fab.gbr, Board-B_Mask.gbr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]
2020-12-01 Board Version 1.0 Review 5
    [Board-B_Cu.gbr, Board-B_Mask.gbr, Board-B_Paste.gbr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]
2020-12-02 Board Version 1.0 Review 6
    [Board-B_Cu.gbr, Board-B_Mask.gbr, Board-B_Paste.gbr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]
2020-12-02 Board Version 1.0 Review 7
    [Board-B_Cu.gbr, Board-B_Mask.gbr, Board-B_Paste.gbr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]
2020-12-02 Added missing bool returns
    [main.cpp]
2020-12-08 Fixed missing leading Zeroes in Frame Data bytes
2020-12-13 CAN Frame from Webpage implemented
2020-12-16 Inverted setup order to prioritize WiFi connection
    [main.cpp]
2020-12-16 Fixed implementation of LEDs to fit the Hardware
2020-12-16 Deleted Debugging serial print
2020-12-16 Fixed CANAdapter false return when sending frame
2020-12-17 Fixed sending frames with DLC=0
2020-12-17 CAN Lib does not allow to receive frames of dlc=0. Error fixed in new implementation of library
2020-12-17 Optimized send buttons in webpage
2020-12-17 Fixed missing DLC in rtr frames display in web
2020-12-18 Board Version 1.1 Fixed Relay Supply, standard Pins for CAN Transceiver and added CAN high and Low Labels
    [Board-B_Cu.gbr, Board-B_Mask.gbr, Board-B_Paste.gbr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]
2021-01-07 Use Case UML Diagrams
2021-01-07 Implemented Switching between OBD or CAN Bus Modes
2021-01-07 Request Status LED in WS implemented
2021-01-08 Auto PID Analysis in JS implemented
2021-01-11 Enum for Filter Modes
2021-01-11 Fixed Comments. Implemented Filter Enum in Lawicel.cpp
2021-01-11 setFiltermode Implemented. Constructor updated for use of Filters
2021-01-11 Changed FILTER struct into filterData typedef
2021-01-11 Implemented Single Filter for Std Frame
2021-01-12 Defined functions for the use of Hardware CAN Filters
2021-01-12 Implemented setACRn and AMRn in Hardware Filter
2021-01-12 Implemented Filter Mode in Hardware Filter
2021-01-12 Changd Filter Data Type into struct
2021-01-12 Switch for Filter Mode
2021-01-13 Fixed Bug: Button is Low-Active Logic
2021-01-13 Board: Yoda Notation in IF-statements
2021-01-14 Added Control List to BOM Excel Table
    [BOM.xlsx]
2021-01-14 Changed Timeout of Websocket Queue. Error handling in case of Full Queue
2021-01-15 Updated BOM with missing component and correct values
    [BOM.xlsx]
2021-01-15 Deleted unused Filter code
2021-01-22 Extracted testing CAN Send Frame in a helper
2021-01-27 Added initializer for ODB switch GPIO
2021-01-29 Added Node-Red Folder, flows and ReadMe
    [PIDFlow.json]
2021-01-29 Added PCB models
2021-01-29 Added Node-Red Images, Dashboard and Info
    [PIDFlow.json]
2021-01-29 Added Frame Polling in Interaction Diag.
2021-02-01 Added Pictures of 3D-Printed Case
2021-02-01 Added 3D Models of Board and Casing
    [Board.step, Casing_Bot.stl, Casing_Top.stl]
2021-02-01 Added parser for buffered incoming frames
2021-02-01 Added explanation of Smart Switching
2021-02-01 Updated Node-Red Flows
    [PIDFlow.json]
2021-02-03 Fixed arrow. Dependency on Arduino
2021-02-03 Changed Resistor values on voltage regulator
    [Netzteil.sch]
2021-02-04 Updated Schematic for exporting as PDF
    [Board.sch, CAN_Transceiver.sch, MCU.sch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]
2021-02-25 #12 Unnecessary Desktop.ini file deleted. Unnecessary Hardware Implementation backup files deleted
    [Board.dsn]
2021-02-25 #13 Added missing Keyword "static" on module scope variables and local functions.
    [main.cpp]
2021-02-25 #13 Fixed Coding Style for variable names.
    [main.cpp]
2021-02-25 #7 Prevent assignment of value to "result" in case of error.
2021-02-25 #10 Fixed Indentation and Doxygen Style in Main.cpp
    [main.cpp]
2023-01-20 Fixed dependencies, include paths and test framework.
